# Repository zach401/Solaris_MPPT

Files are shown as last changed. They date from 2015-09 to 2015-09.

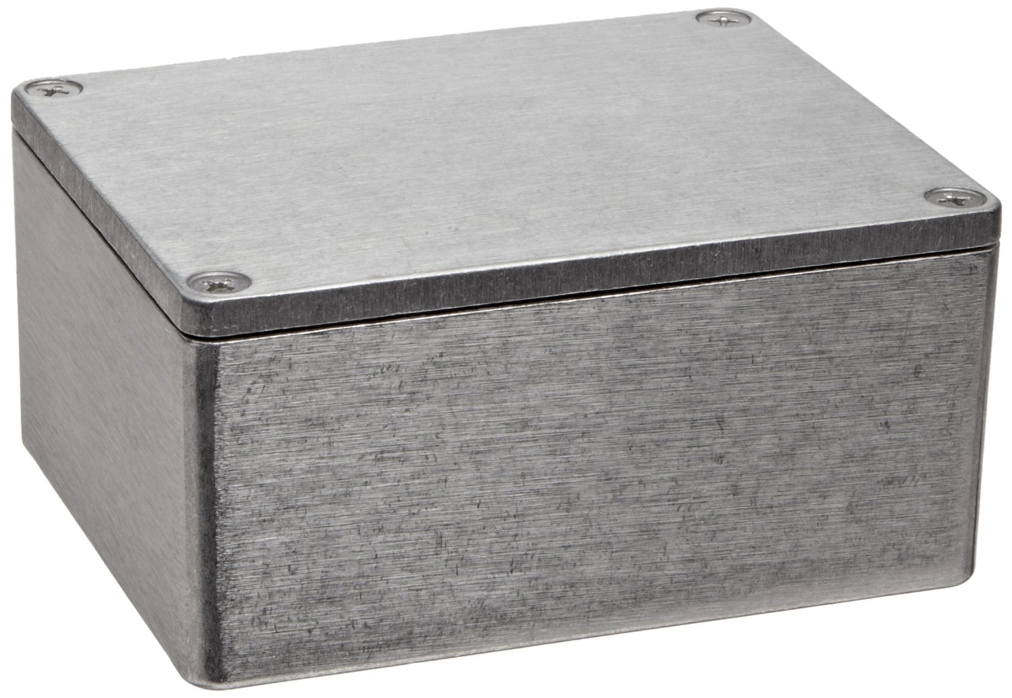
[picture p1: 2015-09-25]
Prototype Pictures, Videos/casing.jpg

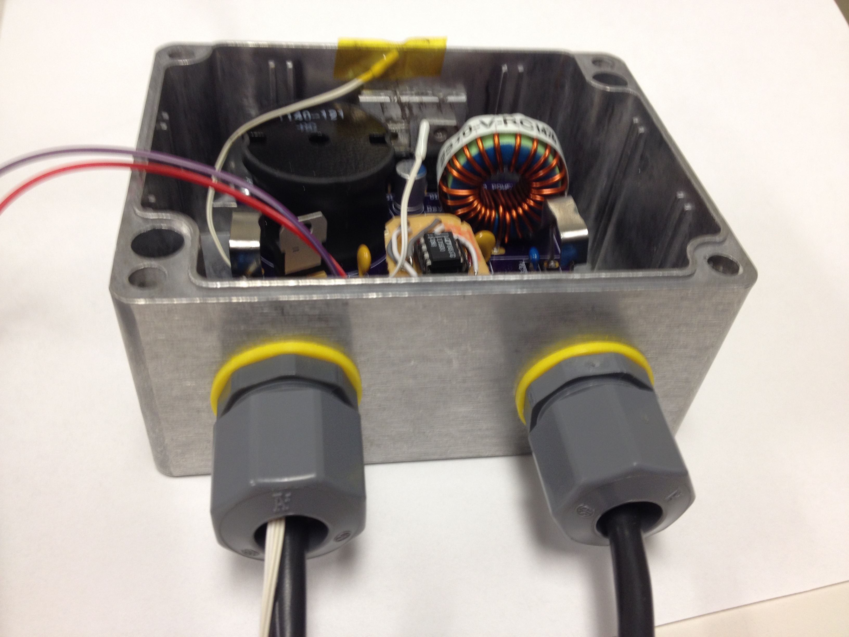
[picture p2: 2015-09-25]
Prototype Pictures, Videos/photo 4.JPG

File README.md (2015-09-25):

# Solaris_MPPT
A low-cost solar maximum power point tracker. 

#Team
Kyle Crouse | Zeke Zumbro | Austin Ricks | Zachary Lee

#Code
The microprocessor using in this project is the TI MSP430G2553 which is standing in the TI MSP430 Launchpad. C code to run the MPPT using the Perturb and Observe algorithm can be found in the Code folder. This is setup as a TI CodeComposer project.

#Electrical Hardware
Designs for the Cuk DC-DC converter, sensors, and printed circuit board for this project as well as datasheets for components can be found in the Electrical Hardware folder. 
*Note that the PCB design is rev1 which had a few mistakes including miswired pins for the OP-AMP read the Errata file for more info.

#Mechanical Hardware
Designs for a waterproof casing and heat-sink for the design can be found in the Mechanical Hardware folder.

#LTSPICE
Simulations of DC-DC converter and sensors.

#Matlab
Matlab files to calculate component values for Cuk and SEPIC DC-DC converters.

#Final Report Documents
This project was begun as a junior design project at John Brown University, as such, a detailed final report and presentation can be seen in this folder.

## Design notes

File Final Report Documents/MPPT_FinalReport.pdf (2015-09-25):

John Brown University

### Development of a Low-Cost Maximum Power Point Tracker for Low-Wattage Photovoltaic Systems

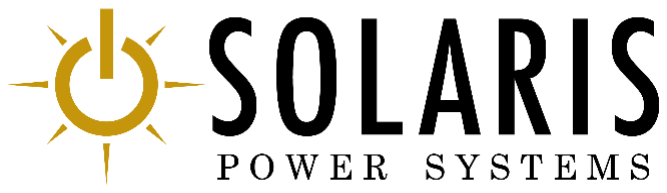
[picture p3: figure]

FINAL REPORT

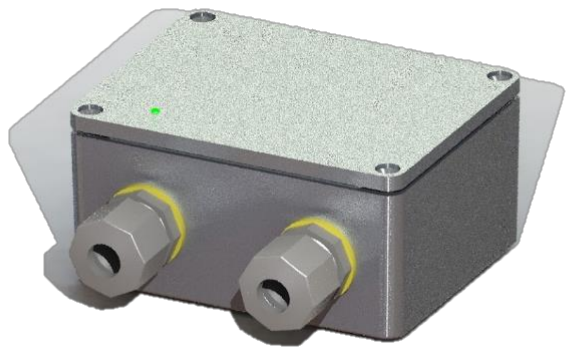
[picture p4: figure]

Kyle Crouse, Zach Lee, Austin Ricks, Zeke Zumbro Professor Kim Cornett
May 5, 2015

May 5, 2015
Final Report
ABSTRACT

The power obtained by photovoltaic panels typically is not the maximum power that could be produced by the panel. Maximum Power Point Trackers (MPPTs) have been developed in order to increase the power output of a panel by setting its operating point to the panel to the point where maximum power is extracted from the panel. The major issue with current Maximum Power Point Trackers is their high cost. The report outlines the design, assembly, and testing of a $91.32 prototype for a 65 W maximum power point tracker. Reasons for the design as well was market considerations are first discussed to justify the need for this design. Initial design parameters including technical and financial considerations are then outline for the project. The design of each subsystem, including the DC-DC converter, current and voltage sensors, algorithm, printed circuit board (PCB), and housing, are then discussed in detail. This design process includes the equations, diagrams and computer simulations used in the design process. Explanation of the construction and debugging process follows this design process. Included in this section is the creation of two small breakout boards, called stamps, which were used to correct errors in the original PCB. The report then outlines the methods used to test the MPPT, including subsystems testing and final design testing. From this testing it was determined that the circuit performed as expected when tested using a 15 W PV panel. From this testing an average power increase of 35.24%, which exceeded the design parameter of 10% power increase. Future work will include testing the design to its full rated power using a 65 W panel. However, all components are designed to exceed this power rating. Additional future work is also outlined, including increasing the efficiency of the DC-DC converter used in this design and decreasing the switching frequency used. A final production cost for 1000 units was calculated to be $40.66 which was below the desired final production cost of $75.

May 5, 2015

CONTENTS
I. Introduction | 1
II. Problem Definition | 2
A. Requirements Breakdown | 3
B. Constraints | 4
C. Testing Plan | 4
III. Technical Solution | 6
A. Brainstorming of Multiple Ideas | 6
B. Selection of Design Ideas to Pursue | 7
C. Technical Analysis & Design Details | 10
1. Electrical Details | 10
2. Mechanical Details | 21
D. Reliability & Safety (FMECA) | 25
E. Prototype Construction & Integration | 32
F. Testing & Verification | 34
IV. Schedule & Modifications | 38
V. Final Budget & Future Production Costs | 39
VI. Future Work Improvements | 42
VII. Conclusions | 43
VIII. Reflection | 43

FIGURES

Fig. 1. Cuk Converter Topology | 11
Fig. 2. LTSPICE Simulation of Ćuk Converter with Varying Duty Cycles | 12
Fig. 3. Voltage Divider with Op-Amp Buffer | 14
Fig. 4. Inverting Amplifier Configuration | 14
Fig. 5. Current Shunt Resistor Configuration | 15
Fig. 6. Ćuk Converter with Integrated Sensors | 16
Fig. 7. Linear Regulator Configuration | 17
Fig. 8. Printed Circuit Board Layout | 18
Fig. 9. Flow Chart of Perturb and Observe Algorithm [1] | 20
Fig. 10. Top View of Enclosure Box and Lid Draft and Dimensions | 21
Fig. 11. Side Views of Enclosure Box and Lid Draft and Dimensions | 22

May 5, 2015

Fig. 12. Heat Spreader, PCB Standoff Screw Draft and Dimensions | 23
Fig. 13. Cable Gland Assembly | 24
Fig. 14. Cable Gland Components Side View, w/o Plastic/Rubber Clamp Bit | 24
Fig. 15. PCB Assembly with Select Components | 24
Fig. 16. Final Product Assembly with Lid | 25
Fig. 17. Final Product Assembly without Lid | 25
Fig. 18. MPPT Test for 15 W PV Panel at Station 10 | 36
Fig. 19. MPPT Test for 15 W PV Panel at Station 9 | 36
Fig. 20. Timeline | 38

TABLES

Table I. Commercial MPPT Prices | 1
Table II. Technical Criteria | 3
Table III. Modified Technical Criteria | 3
Table IV. DC-DC Converter Decision Matrix | 7
Table V. Algorithms Decision Matrix | 8
Table VI. Current Sensor Decision Matrix | 8
Table VII. Voltage Sensor Decision Matrix | 9
Table VIII. Controller Decision Matrix | 9
Table IX. Converter Parameters | 10
Table X. Component Values | 11
Table XI. Ideal Outputs | 12
Table XII. Maximum Specifications for Components | 13
Table XIII. Selected Components | 13
Table XIV. ADC Calibration Data | 19
Table XV. FMECA Summary | 30
Table XVI. Duty Cycle Testing Results | 34
Table XVII. Efficiency Testing Data | 34
Table XVIII. Budget | 39
Table XIX. Bill of Materials | 40

May 5, 2015

I. INTRODUCTION
Photovoltaic (PV) systems are an increasingly popular source of power today, as they can be completely independent of an electrical grid, produce no emissions, and require only the sun as a fuel source. These advantages also make PV systems a viable way to alleviate energy poverty in the developing world. However, those lacking access to a reliable energy are often prohibited by the initial cost required by such PV systems. The use of a maximum power point tracker (MPPT) for PV panels can decrease this initial cost by increasing the efficiency of each panel, thus necessitating fewer panels to achieve the required power budget.
While PV systems are widely recognized as an optimal source of power in developing countries, communities in these countries are yet faced with two issues regarding the implementation of such systems: 1) the power provided by PV systems is inadequate to fulfill the total need for a community, thus necessitating kerosene or other fossil fuels as supplemental power, or 2) the community lacks the necessary funds to make the initial investment for a PV system. A PV system typically consists of one or more PV panels connected to a battery. By introducing an MPPT into a PV system, the efficiency of each panel is optimized, increasing the power output relative to PV systems without maximum power point tracking. To a community presently possessing a PV system, adding an MPPT drastically increases the power produced by the system for the community, reducing the community’s need for fossil fuels as supplemental power. To a community considering the purchase of PV panels, the addition of an MPPT reduces the initial investment required, as fewer panels are necessary to achieve the desired power budget.
This project fits within the Environmental Technology market segment. The target market for this project is home and business owners in the developed and developing world who utilize low-wattage PV systems to provide electricity and reduce their environmental impact. This project is primarily focused on consumers in the developing world who cannot afford MPPTs on the market today. Table I shows the current costs of MPPTs on the market today.

Table I. Commercial MPPT Prices

Name

Max Power
Intake (W)

Price ($)

BZ Products MPPT250 | 300 | 111
Blue Sky 2512i | 300 | 213
Morningstar SunSaver 15 Amp MPPT Solar Charge Controller | 180 | 250
Rogue MPT-3048 | 360 | 350
Morningstar TriStar 30 Amp MPPT Solar Charge Controller | 360 | 355

May 5, 2015

From Table I it can be seen that most MPPTs on the market today cost over $100, which is out of the price range of many in the developing world. A high priced MPPT makes the purchase of an additional panel more cost effective than adding an MPPT. This project seeks to develop a more affordable MPPT to meet this market need. This device will be important for this market as it decreases the cost per watt of PV systems by increasing the power output of a PV system at a lower cost than adding the equivalent capacity by adding additional PV panels. This device will thus help to provide access to affordable electricity in developing regions. The project will also have a broader market toward any PV user desiring to maximize the efficiency of his or her PV system at the lowest cost.
This report details the design, construction, and testing process of a low-cost MPPT appropriate for small PV systems in developing countries. The resulting MPPT is designed to receive as input a PV panel or array with a maximum capacity of 100 W. The MPPT which has been designed is extremely simple and does not include any additional features which would increase cost and add additional points of failure. The design is water resistant and robust against physical damage.
As a result of this project a working MPPT has been developed which has demonstrated the ability to increase the power to a resistive load by an average of 35.24%.The MPPT has been tested extensively with a 15 W PV panel and has been tested on a 65 W panel. Each subsystem of the MPPT has been thoroughly tested, including the DC-DC converter, current and voltage sensors, and housing. Although the initial design parameters were changed after consulting with Dr. Song, all of these new parameters were met with the exception of the efficiency standard for the DC-DC converter. It was found that the DC-DC converter for this design was 75% efficient which exceeded the initial requirements. A detailed user’s manual as well as packaging have also been created for this project.

II. PROBLEM DEFINITION
MPPTs increase the power output of PV panels, however due to the high costs of many on the market they are not economically viable for small solar arrays; this creates a need for a lower cost option. The proposed project would decrease the cost of the MPPT to $75 by utilizing a low-cost microprocessor, low-cost sensing technologies, and by custom designing components as necessary. The MPPT will be designed with widely available, modular components, to allow for ease of maintenance and repair. Additionally, the MPPT will be designed to have a plug-and-play interface, so as to simplify installation and setup. As PV systems are necessarily outdoors, the MPPT will be housed in such a way as to withstand adverse weather conditions, such as rain and extreme temperatures.

May 5, 2015

A. Requirements Breakdown
The initial technical performance criteria for this project can be seen in Table II.

Table II. Technical Criteria
| Min | Max
Vin | 5 V | 38 V
Vout* | 11.8 V 14.4 V
∆Vout | - | 2.5%
P | - | 300 W
∆P | +10% | -
Efficiency | 90% | -
Self-Consumption - | 50 mW
Length | - | 8"
Width | - | 6"
Height | - | 4"

After consulting with our mentor Dr. Ted Song, and doing preliminary research, these criteria were adjusted to more realistic levels for a one-semester undergraduate project. In addition, the load for the project was changed from a battery load to a resistive load. These new criteria can be seen in Table III.

Table III. Modified Technical Criteria
| Min | Max
Vin | 5 V | 40 V
Vout* | 0 V | 25 V
∆Vout | - | N/A
P | - | 100 W
∆P | +10% -
Efficiency | 70% | -
Self-Consumption - | 100 mW
Length | - | 8"
Width | - | 6"
Height | - | 4"

The criteria of Vin was determined based on the minimum and maximum voltage outputs for PV panels in the 100 W range. The criteria for Vout was determined based on realistic values for voltage across the output resistor when tracking the maximum power point. This is the type of battery system expected to be used by the target market, as it is an affordable energy

May 5, 2015

storage technology. The output voltage ripple was determined not be important for this design as the output voltage would fluctuate as the MPPT operated regardless of the output capacitor. However, for calculations to determine the output capacitor an allowable voltage ripple of 2.5% was used. The minimum ∆P criteria of +10% means that the MPPT should increase the power output of the panel by at least 10%. The purpose of the MPPT is to increase the power output of the PV panel, thus this minimum is an important criteria for determining the success of the design. The criteria for minimum efficiency of the DC-DC converter within the MPPT has been set to be 70%. The goal of a MPPT is the increase of efficiency of the PV system, thus inefficiencies within the DC-DC converter must be minimized. However, extremely efficient DC-DC converters are difficult to design and outside the scope of this one-semester project, so an allowable efficiency of 70% is realistic. The criteria for self-consumption, or the power taken to run the MPPT, will be less than 100 mW. This too is important because power used to run the controller and other components contributes to inefficiency of the MPPT, and thus should be minimized. Finally, the mechanical size constraint of 8” x 6” x 4” for the device was determined to reduce the footprint of the device where it is installed and to ensure that the device can be easily transported.
B. Constraints
1) Production cost must not exceed $75. As previously stated, a key goal for this project is to design an MPPT that is substantially lower in cost than comparable MPPTs on the market today, making this a primary constraint on the design.
2) Prototype cost must not exceed $150. Since electrical components and printed circuit board fabrication reduce significantly at production quantities, it is expected that the prototype will cost more than a production model of this MPPT. A $150 budget has been determined for this prototype based on the money provided by John Brown University as seed funding for this project.
3) Prototype must be weather resistant. PV panels are necessarily outdoors, thus making it highly likely that the MPPT will be outdoors as well. Without weather resistance, the MPPT will quickly break down and fail to function. The MPPT may be mounted inside of buildings to which power is supplied, but this is not guaranteed. In circumstances when this is not available, the product will be designed to be weather resistant.
4) Design must prevent electric shock to users. Users should not be shocked when installing the device, nor should technicians be shocked when servicing the device.
5) Prototype must be completed by May 5.
C. Testing Plan
In order to determine if the prototype conformed to the design requirements, tests were designed to analyze each subsystem as well as the system as a whole. Testing of the DC-DC

May 5, 2015

converter subsystem was done first in order to determine proper functionality and an acceptable efficiency. The operation of the DC-DC converter was tested by attaching the input side of the converter to a DC voltage source. An MSP430 was then will be used to provide pulse width modulation (PWM) waveform to the DC-DC converter. The output of the DC-DC converter was then measured across a load resistor using the Digital Multimeter (DMM). Success of the DC-DC converter was determined based on whether or not the output voltage was able to be controlled by the PWM signal provided by the AWG. The efficiency of the DC-DC converter was also tested by measuring the input voltage and current to the DC-DC converter using the DMM to find the input power. This was compared to the output power calculated using the load resistance and output voltage measured using the DMM. The circuit was determined to be successful if the efficiency was greater than 70%.
The controller subsystem was also tested. The first elements of the controller subsystem to be tested was the voltage and current sensors. Each sensor was evaluated by providing to it a known voltage or current using a DC voltage source and resistors. The output of the sensor was then compared to the reading from a DMM to determine if the output voltage of the sensor was linearly related to the input. The output of each sensor was then read using the MSP430 ADC. Linear regression was then used to relate the ADC values to the actual voltage and current values read by the DMMs.
The mechanical case subsystem was also tested. The case subsystem was primarily tested for weatherproofing. To do this the case was sealed and water will then be poured over the case in a way which simulated heavy rainfall. The case was then opened and examined to determine if water was able to penetrate the case. The casing was considered successful if no evidence of leakage is found after testing for 1 hour.
Finally the integrated system was tested. Temperature testing was conducted using the PCB circuit inside of the sealed housing. Two thermocouples were used to read temperature levels as the circuit was given power. Maximum temperatures of the individual circuit components were found from the data sheets. This indicated a maximum circuit temperature of 185℉. Testing results that produce an equilibrium temperature less than the 185℉ maximum will be successful.
The effectiveness of the MPPT will be evaluated by determining the increase in power provided to the load when using the MPPT versus when a resistor is directly connected to the panel. The panels connected to MPPT and resistor will then be swapped so each is connected to each panel. The results of these tests will be compared to eliminate variations from different PV panels. The MPPT was considered successful if the average output power was at least 20% higher than the average output power of the PV panel connected directly to the load.

May 5, 2015

III. TECHNICAL SOLUTION
A. Brainstorming of Multiple Ideas
The basic design of a MPPT has been well established, so there was no need to brainstorm alternatives to this design. However the subsystems of the design had many alternatives. There are six major subsystems for which brainstorming alternatives was necessary. The first of these was the DC-DC converter. Five alternatives for the DC-DC converter were determined based on the converters which were covering in EE3503 Power Electronics. These converters were Buck, Boost, Buck-Boost, Ćuk, and SEPIC. The next major subsystem was the algorithm. Based on previous research three alternatives were established. These were Perturb and Observe, Incremental Conductance, and Fractional Open Circuit Voltage. The next subsystem to be considered were sensors. For current sensors three options were considered; a shunt resistor, a Hall Effect current sensor, and a fiber optic current sensor. For voltage only two alternatives were available. These were using the microcontroller's ADC with a resistive divider, and using a voltage measurement integrated circuit. For the controller subsystem four alternatives were developed; an MSP430, a digital signal processor, an FPGA, and an Arduino.
The final subsystem for which alternatives were brainstormed was the housing. Ideas for housing material included printed ABS, purchased injection molding plastic enclosures, purchased extruded aluminum enclosures with outward facing fins, aluminum sheet metal, and purchased ammunition boxes. At the start, plastic was the favored material because it would be easier to work, would not heat up enough to burn the user, and would meet water-resistance and debris resistant requirements. However, aluminum was chosen because it is not difficult to machine, requires a significant amount of heat to burn the user that the circuit is not expected to produce, can be made to fit all durability requirements, and is able to conduct heat better than typical ABS plastic can. As for cable input and output into the housing, not a lot of valid ideas were thought of that would provide strain relief and weather resistance. The way coax cables are used was looked at as a reference but turned down for lack of application to the product concept. The next idea was to use cable glands, which use a double threaded shell of PVC and a nut that compresses a plastic and rubber bit onto the cable. For heat dissipation, the ideas looked at were vents in the bottom of the housing, a small fan to circulate interior air, and circuit components sinking heat directly into the enclosure wall. For mounting, the ideas were surface mounting, pole mounting, and solar array frame mounting. Finally, the alternatives to have a lid or not to have a lid were determined, including what type of lid attachment should be used. Attachment ideas included clamping using jar hooking clamps on all side or with a hinge on one side, a draw latch with hinge, or screws between the lid and box. Each subsystem was then analyzed to determine what criteria should be used to select each component. The components were then run through a decision matrix in order to determine which alternative would be used.

May 5, 2015

B. Selection of Design Ideas to Pursue
The decision matrix in Table IV outlines the selection of a DC-DC converter topology. Four criteria were developed to evaluate the five alternatives. These criteria were cost, simplicity, inversion, and flexibility. The cost criteria involves the costs of components needed for the DC-DC converter design as well as the size of the PCB required, as this will increase the total cost. A higher score in this category signifies a lower cost. The simplicity criteria involves how difficult the design will be as well as difficulty in controlling the converter. Simplicity scores are higher for designs which do not require driver ICs for high-side switching, as well as for designs with fewer components. The inversion criteria grants higher points to converters which do not invert the output. Finally, the flexibility criteria grants higher scores to converters which are able to handle inputs which are both higher and lower than the output and lower scores to converters which can only increase or only decrease voltages. The points in the total column are highest for the best design, which in this case is the SEPIC and Ćuk converters. Since cost was a prime factor, the Ćuk Converter was finally chosen for this design.

Table IV. DC-DC Converter Decision Matrix

DC-DC Converters Cost Simplicity Inversion Flexibility Total
Buck | 7 | 5 | 10 | 5 | 20
Boost | 9 | 9 | 10 | 3 | 22
Buck-Boost | 7 | 5 | 7 | 10 | 22
Cuk | 5 | 7 | 7 | 10 | 24
SEPIC | 3 | 6 | 10 | 10 | 24

The decision matrix in Table V outlines the selection of a MPPT algorithm for the design. Six criteria were developed to evaluate the three alternatives. These criteria were simplicity, required sensors, computational resources, effectiveness, speed, and flexibility. The simplicity criteria measures the ease with which the algorithm can be implemented in code. The simplicity score is highest for algorithms which are easily implemented and lowest for algorithms which are more difficult to implement. The required sensors criteria involves the number and types of sensors required for the algorithm. Perturb and Observe and Incremental Conductance both score poorly in this area because they require a current sensor and voltage sensor, while Fractional Open Circuit Voltage only requires a voltage sensor. The computational resources criteria measures how much processing power is needed to implement the algorithm. This is measured by the number of operations which are necessary in each loop. A higher score in this category represents fewer operations needed. The effectiveness criteria represents how accurately the algorithm find the correct maximum power point (MPP). This score is highest for the Incremental Conductance method which finds and latches on to the MPP. The Perturb and Observe algorithm is next highest since it

May 5, 2015

find the MPP but oscillates around it. Finally, the Fractional Open Circuit Voltage method is least effective as it only approximates the MPP. The speed criteria represents how quickly the algorithm is able to find the MPP. A higher score in speed means that the algorithm find the MPP faster. The flexibility criteria is rates the algorithms on their ability to work with different PV panels without calibration. Since the Fractional Open Circuit Voltage method relies on specifics about the panel, it scores poorly in this category, while the other two algorithms score well. From the total column in Table V it can be seen that the Perturb and Observe method is preferable, and thus this algorithm was chosen for this design.

Table V. Algorithms Decision Matrix

Algorithms | Simplicity

Required
Sensors

Computational
Resources
Effectiveness | Speed | Flexibility Total
Perturb | and
Observe
8 | 6 | 9 | 9 | 8 | 10 | 50

Incremental
Conductance
7 | 6 | 7 | 10 | 9 | 10 | 49

Fractional Open
Circuit Voltage
10 | 10 | 10 | 6 | 10 | 2 | 48

The decision matrices in Table VI and Table VII outline the selection of current and voltage sensors for the design. The criteria for both matrices are the same: cost, simplicity, reliability, and efficiency. The cost criteria relates to the cost of the sensor or components to build the sensor. A higher score represents a lower cost. The simplicity criteria involves how difficult the sensor will be to design and implement, as well as the ease with which the sensor can be read by the controller. A higher simplicity score represents a simpler design. The accuracy criteria represents how accurate the sensor is relative to the actual value, with a higher accuracy score meaning that the sensor is more accurate. The efficiency criteria measures how much power is consumed by the sensor. A higher score in efficiency represents a lower power consumption for the sensor. From Table VI it can be seen the both the Shunt Resistor and Hall Effect sensor have the same total score. The Shunt Resistor and Amplifier has been selected however, due to greater simplicity. From Table VII it can be seen that the Microcontroller ADC with Voltage Divider method received the highest score and will be used for this project.

Table VI. Current Sensor Decision Matrix

Current Sensors | Cost Simplicity Accuracy Efficiency Total
Shunt Resistor and Amplifier 8 | 7 | 7 | 6 | 27
Hall Effect Current Sensor | 7 | 4 | 8 | 8 | 27
Fiber Optic Current Sensor | 1 | 1 | 10 | 8 | 20

May 5, 2015

Table VII. Voltage Sensor Decision Matrix

Voltage Sensor | Cost Simplicity Accuracy Efficiency Total
Microcontroller ADC and Voltage Divider 9 | 10 | 8 | 6 | 34
Voltage Measurement IC | 7 | 7 | 9 | 9 | 32

The decision matrix in Table VIII outlines the selection of a controller. The criteria for controller selection are cost, processing power, ease of programming, power consumption, and peripherals. For the cost criteria, a higher score in the represents a lower cost. The processing power criteria represents the amount of processing power the controller has, such as its clock speed and the ability to perform tasks in parallel. High scores in this category represent high processing power. The ease of programing criteria takes into account the ease with which the algorithm can be implemented on the controller. This includes the language which is used to program the controller, development environments available to be used when programming the controller, and availability of sample code. High scores in ease of programming correspond to simpler implementation, a strong development environment, and access to sample code. The power consumption criteria takes into account how much power each controller would require. Since self-consumption of the MPPT has been limited to below 100 mW, it is important that power consumption of the controller be kept low. A high score in power consumption relates to a low power consumption. Finally, the peripherals criteria takes into account the presence of peripherals available on the controller, including ADCs, PWM generators, etc. High scores in this category were given to controllers with these peripherals. From the total column of Table VIII it can be seen that the MSP430 microcontroller received the highest score, and will be used as the controller for this project. This also aligns with the SURF grant which is providing additional funds for this project, as the grant specifies that an MSP430 be used.

Table VIII. Controller Decision Matrix

Controllers | Cost Processing Power Ease of Programming Power Consumption Peripherals Total
MSP430 | 10 | 6 | 9 | 9 | 9 | 43
Digital Signal Processor 8 | 8 | 7 | 7 | 10 | 40
FPGA | 4 | 9 | 7 | 5 | 8 | 33
Arduino | 6 | 6 | 10 | 7 | 9 | 38

May 5, 2015

The criteria for housing of the printed circuit board include weather resistance, durability, and prevention of electrical shock to the user. Additional desired characteristics of the housing design include affordability, ease of manufacture, use of common materials to provide for simple and quick maintenance, reversible component attachments, adequate heat dissipation for the PCB, and durable mounting into the PV array circuit. Since the project is still in the design phase, alternatives that match these constraints and goals are not available and additional research will be made that will affect design choices in the future. Housing design manufacture is scheduled for 20 March 2015. Testing is scheduled for 12 April 2015, and the results will affect the final prototype design for final presentation on 5 May 2015. At the time of proposal submission, plastic is the favored material for circuit housing to minimize cost and weight. Metal housing would heat up in the summer, hindering heat dissipation from the circuit, and would need to be properly sealed to prevent rust. A hinged lid with O-ring sealing is an alternative that would allow for ease of access to the circuit while keeping the circuit weather resistant. Additional research and future design alternatives will be included in the online project notebooks.
The criteria for housing of the printed circuit board include weather resistance, durability, and prevention of electrical shock to the user. Additional desired characteristics of the housing design include affordability, ease of manufacture, use of common materials to provide for simple and quick maintenance, reversible component attachments, adequate heat dissipation for the PCB, and durable mounting into the PV array circuit.
C. Technical Analysis & Design Details
1. Electrical Details
Technical analysis of the chosen design began by determining the DC-DC converter parameters needed in the design. These parameters can be seen in Table IX. The values in Table IX were selected based on PV panel characteristics as well as research into parameters of other comparable MPPTs.

Table IX. Converter Parameters
Parameter Minimum | Maximum
Vs (V) | 5 | 38
R (Ω) | 1.44 | 7.5
D | 0.24 | 0.75
f (kHz) | 100 | 200
ΔVC1 (V) | - | 0.1
ΔVC2 (V) | | 0.25

May 5, 2015

A Ćuk Converter topology was selected for the DC-DC converter. A diagram of the Ćuk topology can be seen in Fig. 1.

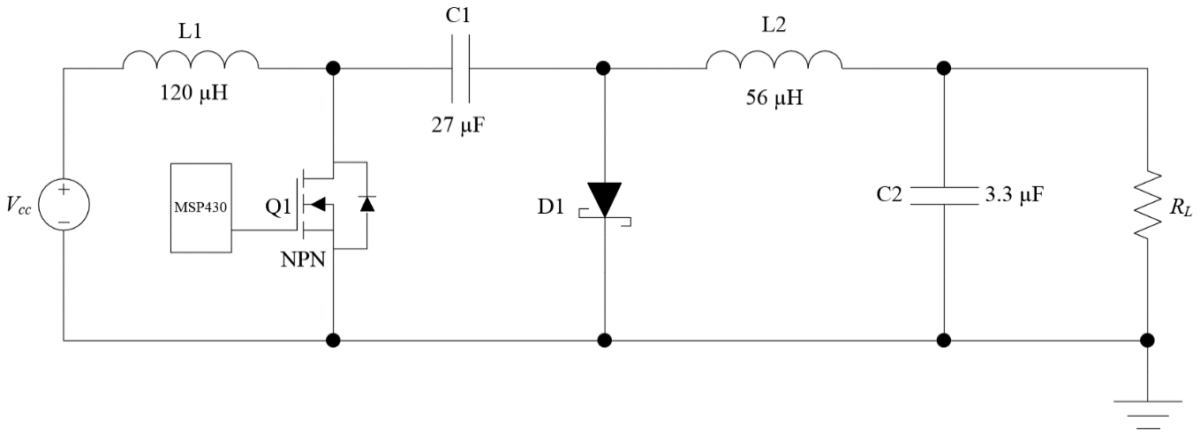
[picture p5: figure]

Fig. 1. Cuk Converter Topology

The values of L1, L2, C1, C2 were found using equations (1) through (4).

L1 ≥

Rmin(1 − Dmin)²

2Dmin ∗ fmin

(1)

L2 ≥

Rmax(1 − Dmin)
2fmin

(2)

C1 ≥

Dmax
Rmin ∗ fmin ∗ ∆VC1

(3)

C2 ≥

1 − Dmin
8 ∗ ∆VC2 ∗ L2 ∗ fmin
2 | (4)

The results of these equations can be seen in Table X. Note that the values in the table are minimum values.

Table X. Component Values
Parameter | Value
L1 | 120 μH
L2 | 38 μH
C1 | 26 μF
C2 | 2.5 μF

May 5, 2015

LTSPICE simulations were then used to determine if the calculated values gave the desired function of the circuit. This was done by modeling the circuit in LTSPICE then using the STEP command to vary the duty cycle of the MOSFET from 20% (teal) to 70% (grey). The plots of the DC-DC convert output for the varying duty cycles can be seen in Fig. 2. A table of the ideal output for each duty cycle can be seen in Table XI. These values were calculated using equation (5) which is the ideal relationship between input and output for a Ćuk converter. By comparing the values from Fig. 2 and Table XI, it can be seen that the circuit functions as expected. The small discrepancies between the ideal output and the simulated output are due to non-ideal switches, including the voltage drop across the diode.

Vo = Vs ( D
1−D) | (5)

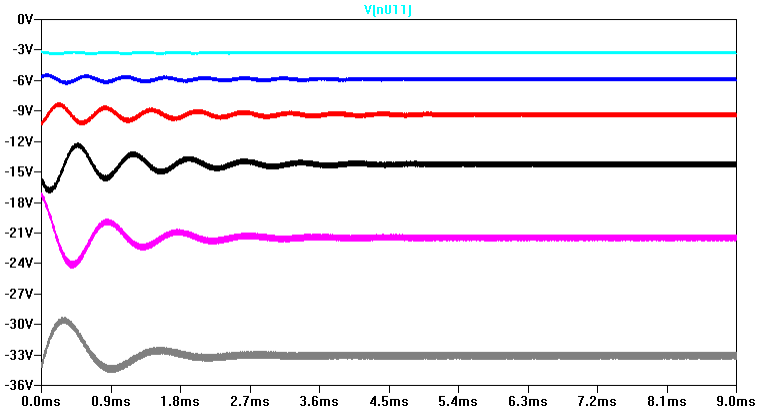
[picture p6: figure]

Fig. 2. LTSPICE Simulation of Ćuk Converter with Varying Duty Cycles

Table XI. Ideal Outputs
Duty Cycle | Ideal Output | Color
20% | -3.75 | Teal
30% | -6.42857143 | Blue
40% | -10 | Red
50% | -15 | Black
60% | -22.5 | Pink
70% | -35 | Grey

May 5, 2015

After it was determined that the circuit functioned as designed, maximum current and voltage rating for each component were determined from the LTSPICE model. These max specifications can be seen in Table XII.

Table XII. Maximum Specifications for Components
Component | Max Voltage (V) | Max Current (A)
L1 | 16 | 8
L2 | 21 | 3
D | 20 | 10
C1 | 20 | 9
C2 | 20 | ~0.5
M1 | 27 | 10

Using the minimum values from Table X and the specifications from Table XII components were selected from www.digikey.com. Values and specifications of the selected components can be seen in Table XIII.

Table XIII. Selected Components
Component | Value | Max Voltage (V) | Max Current (A)
L1 | 120 uH | - | 9.9
L2 | 56 uH | - | 10.2
D | - | 60 | 10
C1 | 27 uF | 63 | -
C2 | 3.3 uF | 25 | -
M1 | | 75 | 100

In addition to the DC-DC converter. Voltage and current sensor were also needed for this design. It was determined that using the ADC built in to the MSP430 offered the easiest and lowest cost solution for voltage and current sensing. A reference voltage of 1.5 V was selected for the ADC. In order the scale the input voltage from a range of 0 to 38 V to a range of 0 to 1.5 V, a voltage divider was used. A diagram of this resistive divider topology can be seen in Fig. 3.

May 5, 2015

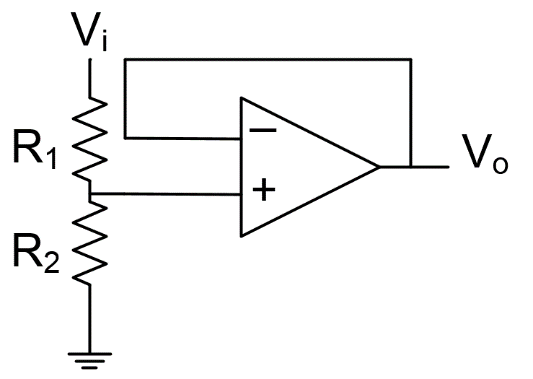
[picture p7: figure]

Fig. 3. Voltage Divider with Op-Amp Buffer

It was determined that a voltage of 64 V should correspond to 1.5 V on the voltage divider. An input/output ratio of 0.0234 was thus determined for the voltage divider. Using equation (6), values of R1 = 470 kΩ and R2 = 11 kΩ were selected from available resistors. This corresponded to an input/output ratio of 0.029. Large resistors were selected for this application in order to limit current through the voltage divider. An OP-AMP was used to buffer the output of the voltage divider before passing the signal to the ADC for reading.

Vo
Vi

= R2
R1+R2

(6)
For the output voltage sensor the voltage needed to be inverted as well as scaled since the output of a Ćuk converter is negative. This was accomplished using an OP-AMP inverting amplifier configuration. This configuration can be seen in Fig. 4. Equation (7) can be used to find the input/output relationship for the inverting amplifier. For ease of programming, it was determined that it was best to keep the same ratio for both input and output voltage sensors. Thus using (7) the values of R1 and R2 were determined to be R1 = 47 kΩ and R2 = 1.1 kΩ. Lower values were selected for R3 and R4 versus R1 and R2 since these resistors did not provide a path to ground, and thus excess current traveling through them was not a concern.

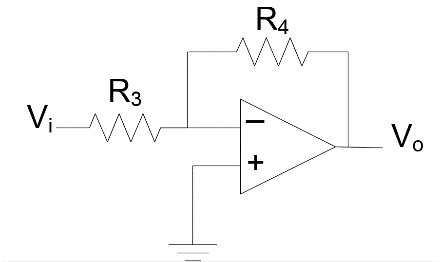
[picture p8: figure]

Fig. 4. Inverting Amplifier Configuration

Vo
Vi

= − R4
R3

(7)

A shunt resistor was determined to be the easiest way to measure current in the design. A shunt resistor is a small resistor which is placed in series with the load. The current traveling through the load is proportional to the current flowing through the load. A 5 mΩ shunt

May 5, 2015

resistor was chosen. However, even at max rated current of 10 A, the voltage across this 5 mΩ resistor would be only 50 mV. In order to amplify this signal a current shunt monitor was used. This current shunt monitor amplified the voltage across the resistor with a gain of 20, thus putting the signal within a range which could be read by the ADC. A diagram of this current sensing topology can be seen in Fig. 5.

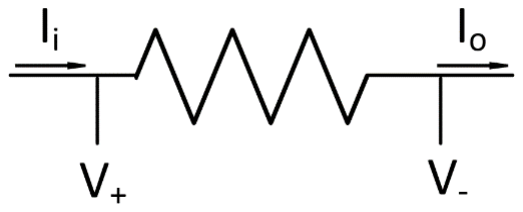
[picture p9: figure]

Fig. 5. Current Shunt Resistor Configuration

The Ćuk Converter and sensor circuits were then integrated into a final circuit. A diagram of this circuit can be seen in Fig. 6.

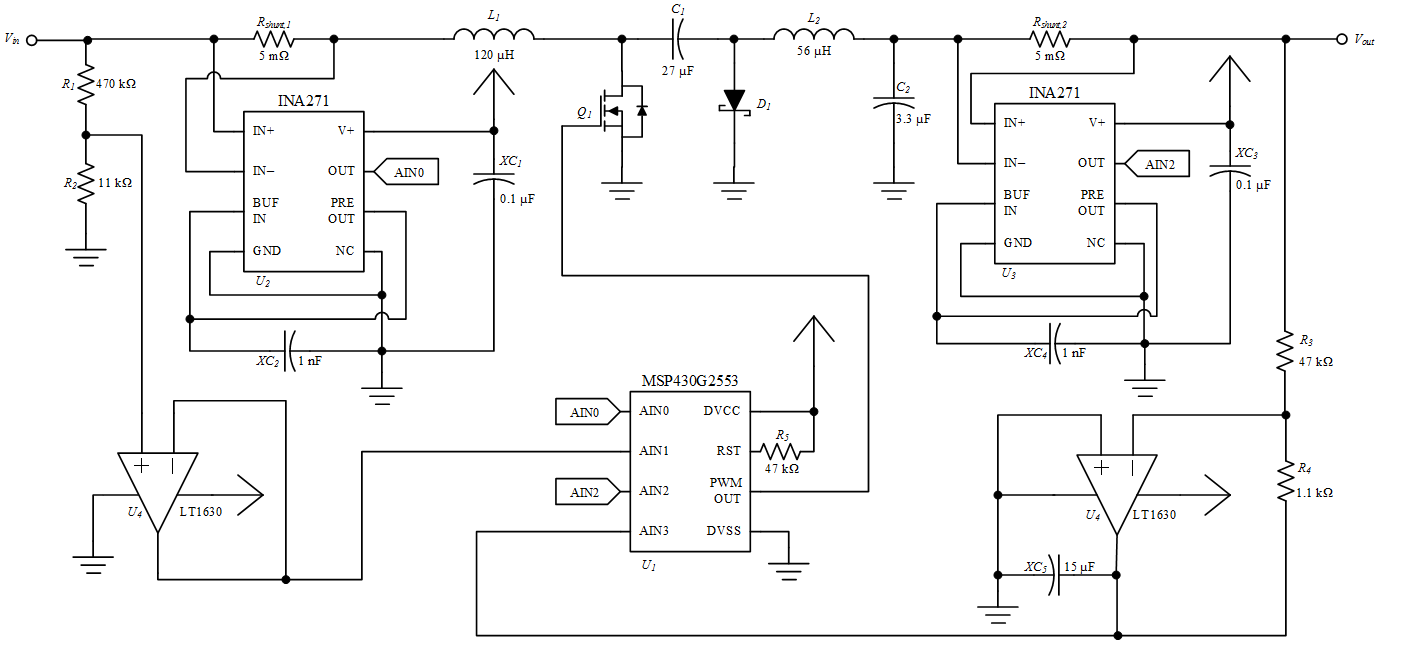
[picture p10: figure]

Fig. 6. Ćuk Converter with Integrated Sensors

In order to power the MSP430 as well as the op-amps and current shunt monitors a linear regulator was chosen. This linear regulator lowers the input voltage to a constant 3.6 V. This voltage was chosen as it is high enough to fully saturate the logic level MOSFET used in this design, which is important for using the MOSFET as a switch. Because a 3.6V regulator was not available, a variable output regulator was purchased. The voltage output of this regulator was determined based on two external resistors using the configuration in Fig. 7 and equation (8). By setting Vout equal to 3.6 and solving for R2/R1 it was found that that ratio of R2 to R1 should be approximately 1.88. Using resistor values which were then chosen from available resistors. R1 was selected to be 2 kΩ and R2 was selected to be 3.8 kΩ.

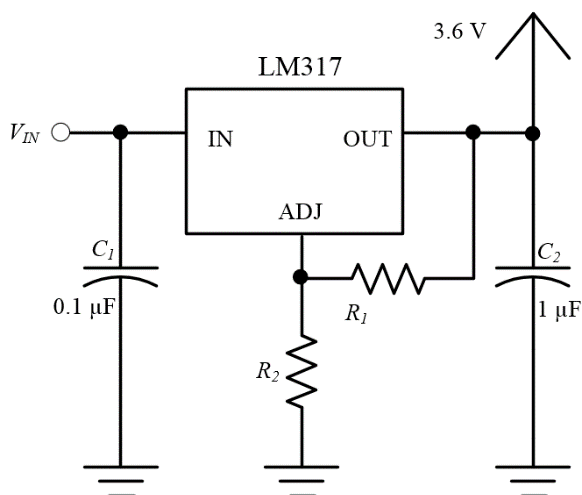
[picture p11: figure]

Fig. 7. Linear Regulator Configuration

Vout = 1.25(1 + R2
R1
) | (8)

A printed circuit board was then designed for the circuit. The required trace widths were first calculated using an online tool [2]. Two net classes were defined. The first was a power class which could handle up to 10 A of current. It was determined that having these power traces on both the top and bottom of the board would best allow for this large amount of current which minimizing the needed trace width. The second net class was a data class which did not need to handle high currents, but instead moved signals across the board. Each of the components selected from Digi-key were modeled in Eagle then used to create a schematic and then board layout. For the board layout the autorouter function was first used to begin routing traces. Traces which could not be completed by the autorouter were then completed by hand. The final PCB layout can be seen in Fig. 8.

March 12, 2015

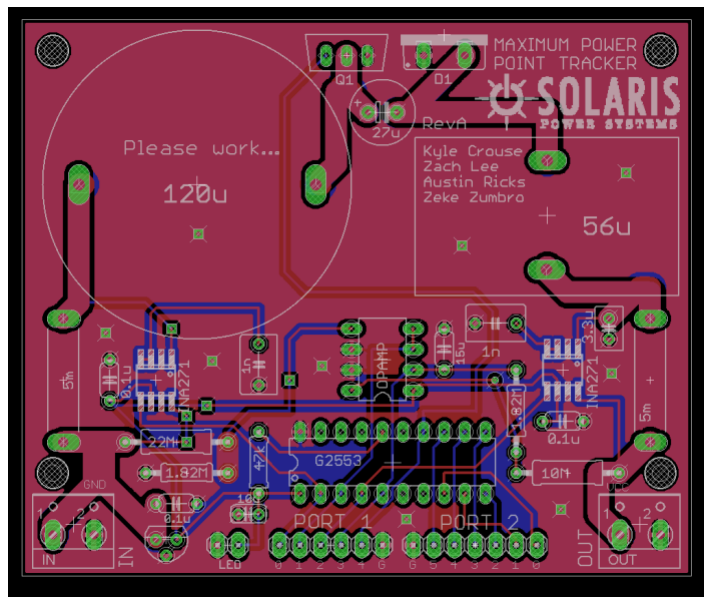
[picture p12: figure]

Fig. 8. Printed Circuit Board Layout
In addition to the electrical hardware components of this design, the software which runs on the MSP430G253 is extremely important. It is this software to enables the design to track the maximum power point, and provides the DC-DC converter with the switching signal that it needs to function. The code for this design can be seen in Appendix A. The code can be roughly divided into three sections; initialization, sensor reading, and maximum power point tracking.
The first of these divisions, initialization, contains the code which sets up the microcontroller and required peripherals. This initialization includes the functions Setup_MSP, Setup_ADC, Setup_PWM, and Setup_Timer. The initialization of each peripheral was divided into separate functions to that it was clear where the settings for each was located. This allows for greater readability of code and will make maintaining this code easier in the future. The clock speed of the MSP430 was set to 16 MHz in order to allow for the maximum number of duty cycle steps when running pulse width modulation (PWM) at 100 kHz. The ADC was configured to read 4 channels 32 times consecutively. This allowed for sampling each of the 4 sensors as well as averaging over 32 samples in order to take more accurate readings. The number of samples was chosen to be 32 since 32 is a power of 2 and thus division by 32 can be accomplished using a bit-shift which is more efficient than a normal integer division. TimerA0 was configured for PWM, and set to a frequency of 100 kHz by setting TACCR0 to
160. This value was determined by dividing the clock frequency, 16 MHz, by the desired frequency 100 kHz. PWM was set up to output on P1.6.
The next division of code was reading from the sensors. This section consists the function Read_ADC and the interrupt service routine (ISR) for the ADC. When Read_ADC is called, the ADC enable conversion flag is first cleared. The function then waits if the ADC is currently busy. The data from the ADC is then directed into an array of unsigned integers, and sampling and conversion is started. The processor is then placed into low power mode 3. When the ADC has finished sampling, the ADC ISR is called and the processor exits low power mode. After ADC measurements have been taken, the 32 samples from each sensor are first added together, then this value is divided by 32 to find the average. This average is then put through a linear equation to relate the ADC value for each sensor to its actual measurement (volts or amps). This equations were determined using linear regression from data taken during testing. In order to get this data, known voltages were fed into the input of the circuit. The current in, as well as the voltage and current out were then measured using digital millimeters. At the same time the ADC measurements taken from the sensors on the board were also read. The data from this experiment can be seen in Table XIV. The linear regression tools from Microsoft Excel were then used to find equations relating voltage or current to the corresponding ADC value. The equations relating ADC reading and actual measurements can be seen in equations (9) through (12).

Table XIV. ADC Calibration Data
Input | Output

Current (A)

Current
ADC
| | Voltage (V) | Voltage ADC | Current (A) | Current ADC | Voltage (V) | Voltage ADC
0 | 3 | 0 | 11 | 0 | 12 | 0 | 8
0.043 | 7 | 0.5 | 11 | 0.046 | 12 | 0.101 | 6
0.157 | 12 | 1 | 18 | 0.17 | 10 | 0.37 | 7
0.296 | 23 | 1.5 | 25 | 0.307 | 15 | 0.667 | 8
0.46 | 32 | 2 | 32 | 0.457 | 29 | 0.994 | 14
0.646 | 42 | 2.5 | 41 | 0.628 | 41 | 1.36 | 20
0.84 | 55 | 3 | 48 | 0.8 | 55 | 1.74 | 28
1.06 | 75 | 3.5 | 57 | 0.999 | 72 | 2.16 | 35
1.28 | 91 | 4 | 66 | 1.18 | 88 | 2.57 | 42
1.53 | 111 | 4.5 | 71 | 1.39 | 104 | 3 | 49
1.84 | 136 | 5 | 78 | 1.62 | 124 | 3.5 | 58
2.18 | 163 | 5.5 | 91 | 1.88 | 145 | 4.05 | 68
2.54 | 191 | 6 | 95 | 2.12 | 165 | 4.6 | 77
Iin = 0.013459IinADC + 0.01594 | (9)
Vin = 0.066097VinADC − 0.27437 | (10)
Iout = 0.013002IoutADC + 0.019945 | (11)
Vout = 0.061412VoutADC − 0.05239 | (12)
The final division of the program for this design was the actual maximum power point tracking function. Many MPPT functions were developed, however the one chosen for this design utilized the simplest MPPT algorithm, Perturb and Observe. A flow chart of the Perturb and Observe algorithm which was provided by Microchip can be seen in Fig. 9 [1]. In the Perturb and Observe algorithm the MPPT can be in one of two states, incrementing or decrementing. If the MPPT is in the incrementing state, then the duty cycle was last increase, if it is in the decrementing state, then the duty cycle was last decreased. In order to determine if the duty cycle would be incremented or decremented, the current instantaneous power was compared to the previous instantaneous power, if the power increased, then the state would remain the same and the duty cycle would be incremented or decremented based on its state. If the power instead decreased then the state was toggled, and the duty cycle would be incremented or decremented accordingly.
In order to make sure that the duty cycle never left its allowable range, if statements were used to make sure that the duty cycle was never incremented beyond its max duty cycle or decremented beyond it minimum duty cycle. These maximum and minimum duty cycles were set at 80% and 20% respectively. If the duty cycle was supposed to be incremented, but was already at its maximum value the duty cycle was instead decremented and the state was changed to decrement. The opposite was done if the duty cycle was supposed to be decremented but was already at its minimum value. This ensured that the MPPT would never get stuck at its maximum or minimum duty cycle.

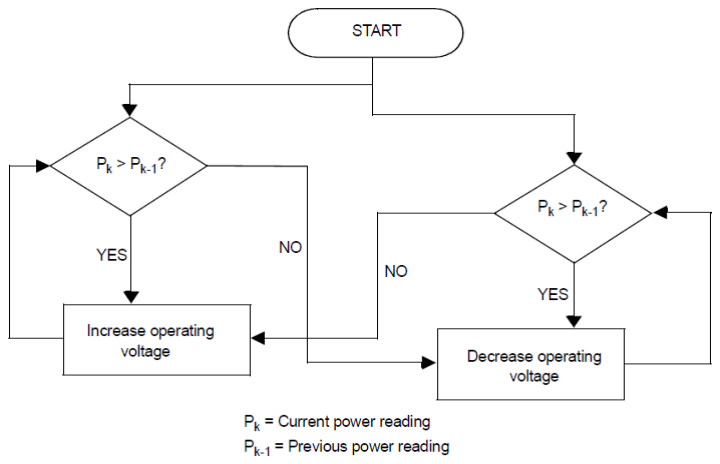
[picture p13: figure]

Fig. 9. Flow Chart of Perturb and Observe Algorithm [1]

2. Mechanical Details
The mechanical aspect of the MPPT began with the following requirements: weatherproofing including water resistance and the ability to withstand high temperatures, protection for the circuit against small impact and rough transportation, and adequate heat dissipation from the circuit to the outside air. A couple of ideas for housing material included printed ABS, purchased injection molding plastic enclosures, purchased extruded aluminum enclosures with outward facing fins, aluminum sheet metal, and purchased ammunition boxes. The choice was made to purchase a NEMA 4 die-cast aluminum enclosure. NEMA 4 is a rating from the National Electrical Manufacturers Association that ensures protection to the user from hazardous part, protection to the enclosure interior from dust, dirt, water, and ice formation. This rating completely fulfills most of the housing design requirements. The purchased enclosure offers the following benefits to the product design:
x The die-cast aluminum is an excellent heat conductor and will dissipate heat from the circuit directly to the outside air.
x The removable lid allows the user access to the circuit for installation and maintenance.
x Mounting holes are available at opposite corners of the box to allow the enclosure to be screwed directly onto a surface.
x A silicon gasket is used that will firmly and durably seal the enclosure with the lid on and tightened.
x Board mounting holes are available inside the box to securely attach a PCB directly to the enclosure.

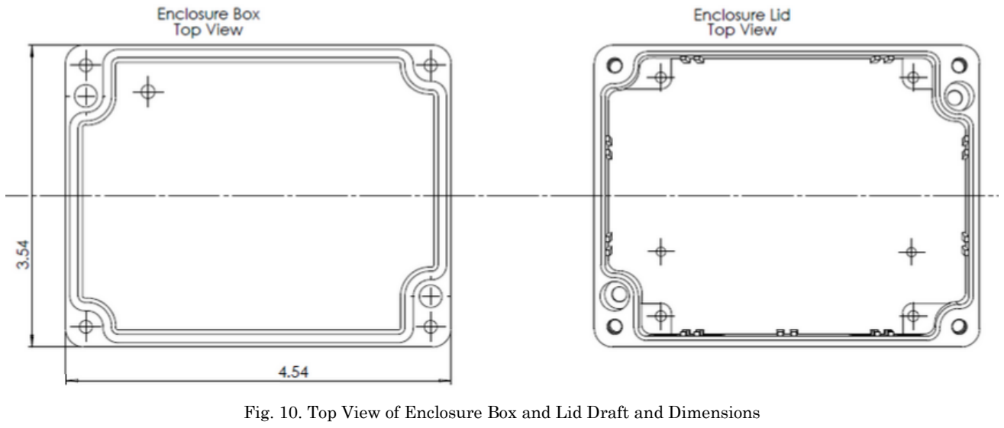
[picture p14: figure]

Fig. 10. Top View of Enclosure Box and Lid Draft and Dimensions

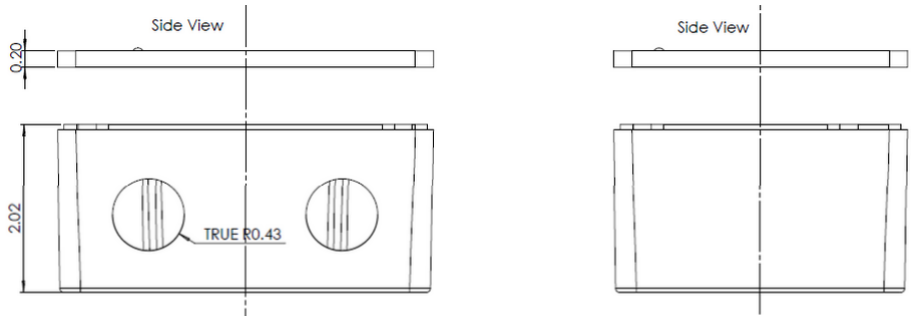
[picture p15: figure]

Drawings and general dimensions for the box and lid are included below in Fig. 10 and Fig. 11.
As shown in Fig. 10 and Fig. 11, additional holes were drilled in the enclosure to fit product needs. Two large holes with a 0.86in diameter were drilled on the side of the box for the use of cable glands. Two small holes were drilled in the bottom of the box for screws to come up and screw into PCB standoffs, securing the PCB to the enclosure. Finally, a small hole was drilled in the lid for an LED circuit function indicator. The PCB is mounted inside of the box with one side screwed into the mounting holes in the box itself. When the enclosure was ordered, there was no expectation of using the mounting platform provided. However, one side of the PCB mounting holes line up almost perfectly with those of the box. A dremel sanding bit was used to widen the holes slightly and then M3.5 x 6mm screws could be used to attach at least half of the PCB to the box. The PCB was not as wide as the enclosure was and did not reach the mounting holes on the other side. Therefore, double side standoffs were used. Initially, aluminum standoffs were used until it was discovered that the PCB mounting holes are very close to the soldering connections for the current sensors and the aluminum would make electrical contact with the circuit. So plastic insulated standoffs were purchased. Screws were used to attach the PCB to the upper half of the standoffs, and then holes were drilled into the bottom of the box as stated earlier and screws came up from the outside of the box into the bottom half of the standoffs. This mounted the PCB at four corners to the enclosure box. Drafts of the standoff and bottom screws are shown below in Fig. 12. Also shown is the heat spreader. This heat spreader was created from a simple 6ft long rolled piece of aluminum purchased at the local hardware store. A small section was cut off and ground flat and smooth to act as a heat spreader between the MOSFET and diode heat sink surfaces and the enclosure box wall. The gap between the heat sink surfaces was large enough that two heat spreaders were required face to face. Thermal grease was used between every face to face contact to minimize air gaps and maximize surface to surface contact and thus heat dissipation.

Fig. 11. Side Views of Enclosure Box and Lid Draft and Dimensions

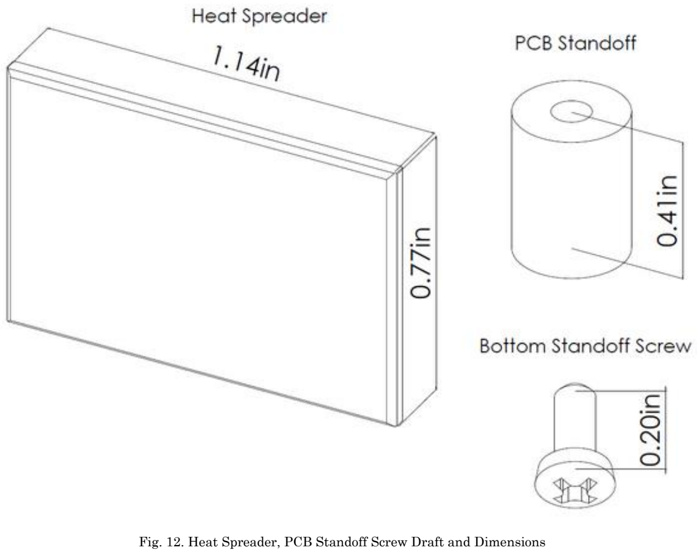
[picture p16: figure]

Input and output cabling between the panel, circuit, and load provided the challenge of figuring out how to make weatherproof and strain relieving cable connections. Cable glands were the solution for both of these requirements. The cable enters the gland body, the rubber washer is placed on the cable gland and butted up against the outside of the enclosure, the lock nut is placed on the gland body thread inside of the box and tightened up against the box wall, and the nut is tightened. Tightening the gland nut clamps a piece of plastic and rubber onto the cable. The plastic grabs the cable for strain relief and the rubber forms a waterproof seal around the cable. The minimum cable size allowed by the cable glands purchased is 0.2in in diameter. This pertains to a 4 AWG cable, not considering insulation. The cable used for testing was 0.21 inches in diameter and sheathed three 20 AWG cables. Drafts for the cable gland components are shown below in Fig. 13 and a rendering is shown in Fig. 14.

Fig. 12. Heat Spreader, PCB Standoff Screw Draft and Dimensions

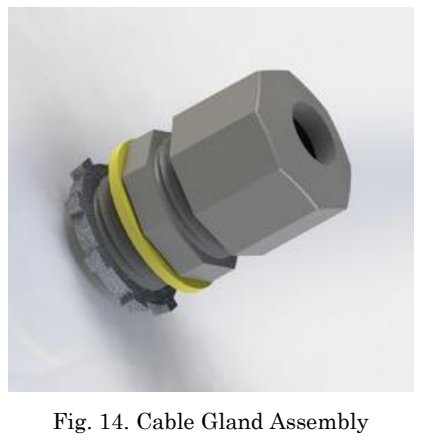
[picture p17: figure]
Fig. 14. Cable Gland Assembly
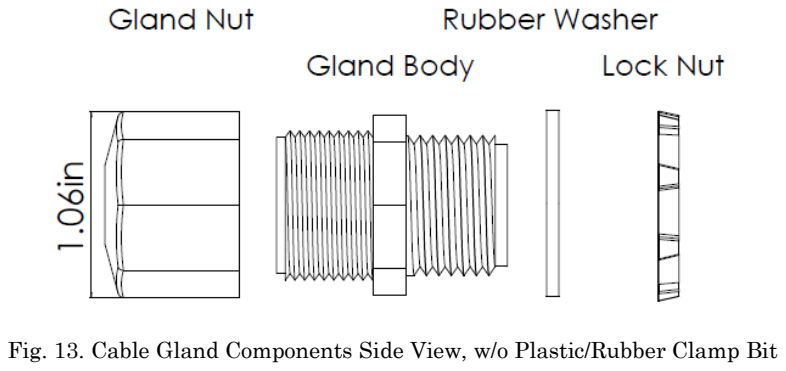
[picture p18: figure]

The printed circuit board and select circuit components were modeled in SolidWorks for use in a final product assembly. This PCB assembly is shown below in Fig. 15. It will be used in final models to indicate the use of heat spreaders, standoffs, and proximity to enclosure walls and cable glands. The MOSFET and diode were chosen to be modeled because they played a crucial role in heat dissipation. The inductors were modeled to indicate the height of the circuit. Finally, the pins were modeled because they were simple to make.
A final assembly is shown below in Fig. 16 and Fig. 17.

Fig. 13. Cable Gland Components Side View, w/o Plastic/Rubber Clamp Bit

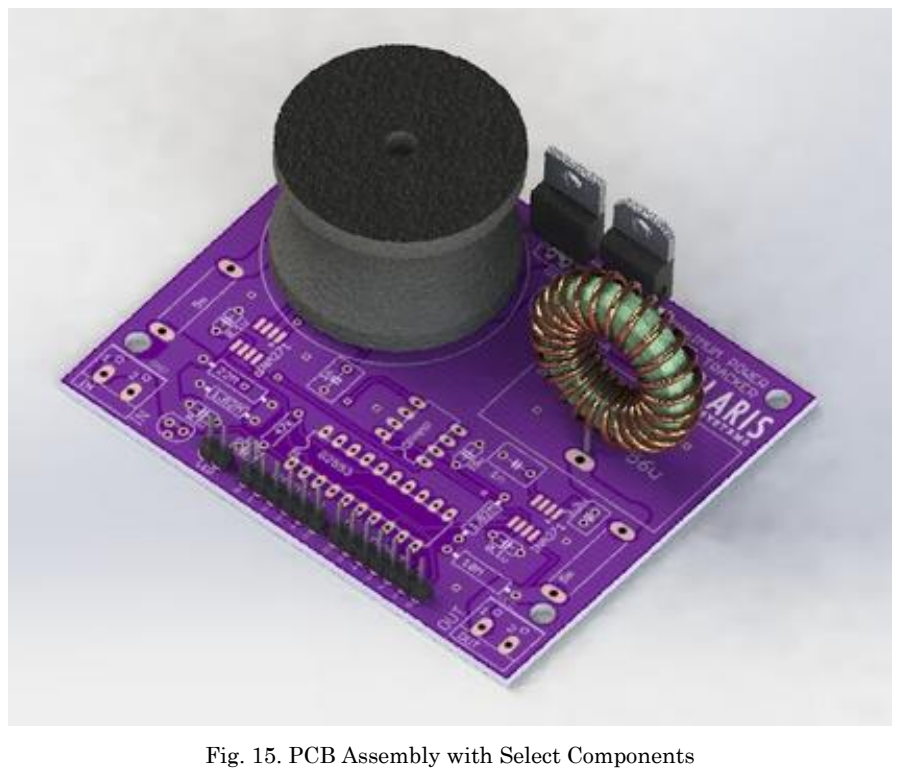
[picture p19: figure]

Fig. 15. PCB Assembly with Select Components

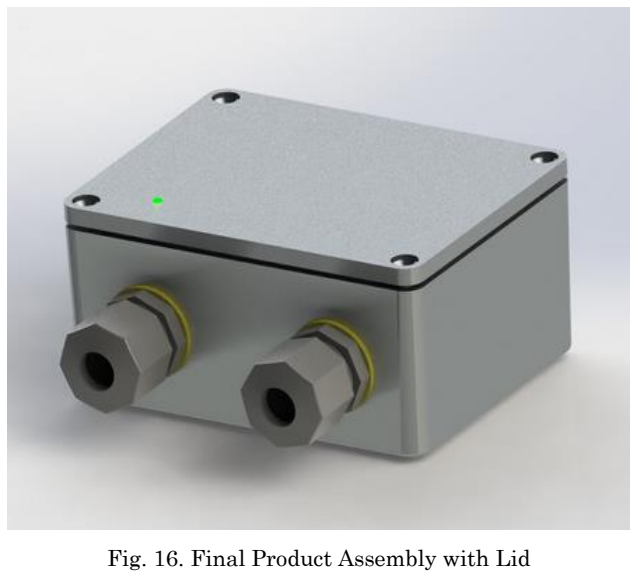
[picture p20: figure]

D. Reliability & Safety (FMECA)

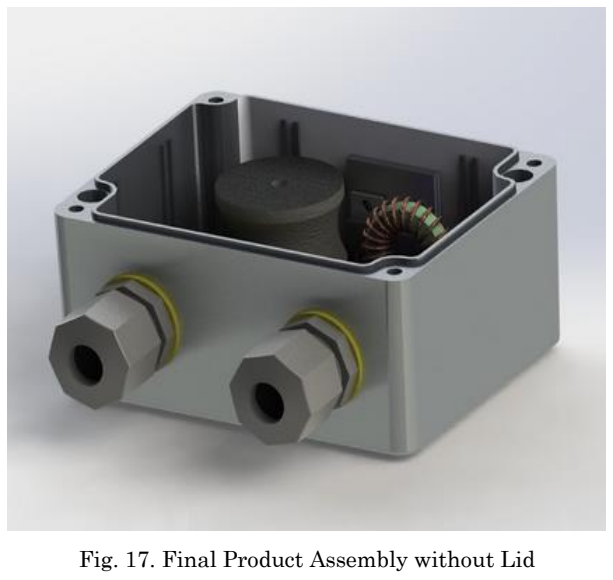
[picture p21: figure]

The FMECA has been divided into seven major items, which account for the major subsystems of the device. For each item, the failure modes were determined, followed by the failure causes, and failure effects. Given these three attributes, a severity index of value 1 to 4 was assigned, 1 being insignificant, 2 being marginal, 3 being critical, and 4 being catastrophic. A probability index of value 1 to 4 was assigned, 1 being extremely remote, 2 being remote, 3 being reasonably probable, and 4 being probable. A third index, criticality, was determined by multiplying the severity and probability indices to give further guidance for ranking potential failures. Given these rankings, control measures were determined to limit the possible failure modes.
i. Current Sensors
Shunt resistors can fail due to a flow of current greater than the specified rating. However, since the resistors have such a low resistance, they are rated for extremely high amounts of current, thus the only likelihood of them failing is due to a physical flaw within the resistor. A physical flaw would cause the resistor to fail, producing an open circuit, thus separating the input from the DC-DC converter. This is not harmful to the PV panel or the DC-DC converter, however, it does result in a non-functioning device, thus a severity of 2 has been assigned. A shunt resistor can also fail by a short circuit due to improper placement or soldering, which causes the microprocessor to be unable to measure the current flowing into the converter. This then affects the power point since it can no longer be tracked by the processor, resulting in an improperly functioning device with unpredictable results. Given these considerations, a severity of 3 and a probability of 1 has been assigned. The most practical way to limit either of these failure modes is to ensure the use of quality sensors.
Fig. 16. Final Product Assembly with Lid | Fig. 17. Final Product Assembly without Lid

ii. | Voltage Sensors
| The voltage sensor is created by two large resistors functioning as a voltage divider, which the analog-to-digital converter can then use to sense the voltage. These resistors can fail open if too much power is supplied to the resistors, causing them to burn out. This would hinder the microprocessor from sensing the voltage, resulting in an improperly functioning device with unpredictable results, thus a severity of 3 and a probability of 1 has been assigned. These resistors can also fail by creating a short circuit to ground, caused by an applied voltage higher than the rating. This would then short the entire panel to ground. This does not harm the panel, however, it does result in a non-functioning device, and thus a severity of 2 and a probability of 1 has been assigned. The most practical way to limit either of these failure modes is to ensure the use of quality sensors.
iii. | DC-DC Converter
| While the DC-DC converter contains numerous components, the MOSFET and diode were concluded to be the most vital when considering failure.
| The MOSFET has two failure modes: open circuit and short circuit. An open failure can be caused by overcurrent or overvoltage from the photovoltaic array and results in no output voltage. A lack of output voltage damages no components or equipment, but results in a non-functioning device, thus a 2 was chosen for severity. A probability of 2 was chosen, as this failure mode is remotely likely to happen given consistent use over a span of time. A closed circuit failure of the MOSFET can be caused by overcurrent and results in the input source being shorted. Shorting a photovoltaic panel results in no damage to the panel, but does result in a non-functioning device, thus a 2 was chosen for severity. A probability of 2 was chosen, as this failure mode is remotely likely to happen given consistent use over a span of time. These failure modes can most practically be limited by ensuring appropriate safety factors in current and voltage for the MOSFET.
| The diode also has failure modes of open circuit and short circuit. A short circuit is caused by overvoltage when the diode is in reverse bias. A short across the diode results in no output voltage. A lack of output voltage damages no components or equipment, but results in a non-functioning device, thus a 2 was chosen for severity. A probability of 2 was chosen, as this failure mode is remotely likely to happen given consistent use over a span of time. An open circuit failure of the diode is caused by continual overvoltage after the diode has reached a short circuit failure. An open across the diode results in no output voltage as well as overvoltage across the other components. This would likely damage the components, leading to a more severe failure. Additionally, this results in a non-functioning device, thus a 4 severity. A probability of 2 was chosen, as this failure mode is remotely likely to happen given consistent use over a span of time. These failure modes can most practically be limited by ensuring the use of a quality diode.
iv. | Microprocessor
| The microprocessor is the brain of the maximum power point tracker. It runs the software which reads inputs from the current and voltage sensors and uses this to adjust the duty cycle of the switched mode DC-DC converter.
| The microprocessor can fail in two ways. The first of these failure modes is lack of power. Three possible causes for lack of power to the microcontroller have been identified. The first of these is that there is an alternative path to ground which is diverting current from the microcontroller and preventing the microcontroller from receiving the necessary voltage. This could be caused by any component failure which shorts the input source, such as a short circuit of the input voltage sense resistor, or a short of the MOSFET. Alternatively, lack of power to the microcontroller could be caused by not having a PV panel attached to the MPPT or voltage input from the panel being below the cutoff of the microcontroller regulator. As there are many causes for this failure mode, a probability of 3 was assigned to this failure mode, signaling that it is fairly likely to happen. However, the severity of failure is a 1, as in most cases lack of power to the microcontroller only happens when the MPPT should not be functioning anyway, and the microcontroller will not be damaged by lack of power. Finally, lack of power to the microcontroller could be caused by failure of the linear voltage regulator. In order to avoid this, a reliable linear regulator will be chosen, also the probability of failure modes which will cause a short of the input panel will be minimized.
| A second failure mode for the microcontroller is power overload. This can result from failure of the linear regulator. The severity of this failure is a 3, since power overload will damage the microcontroller, and possibly destroy it. However, since linear regulators are designed to fail in such a way as to protect the loads they are attached to, this failure mode is very unlikely to occur, so it was given a 1 for probability. This failure mode will be controller by selecting a reliable voltage regulator.
v. Software
| The software for this project is as important as the microcontroller which runs it. Three possible failure modes of the software were identified. The first of these failure modes was variable overflow errors. These errors can occur whenever something is added or subtracted from a variable so that it overflows it allotted number of bits. This can cause errors in software such that variables cannot be accurately read, which can affect the ability of the software to identify the maximum power point. With proper software design, it is unlikely that these errors will occur so a probability of 1 was assigned to this failure mode. If this error does occur, the system may not be able to find the MPP, however lasting damage will not be done, as resetting the microcontroller should solve the problem, thus a severity of 1 was assigned to this failure mode.
A second failure mode of the software will be failure to find the MPP. The primary cause of this type of error will be false peaks as the software searches for the MPP. This is fairly likely to occur as transients from changing the switching duty cycle and changes in weather conditions can cause false peaks in the power calculation, so a probability of 3 was assigned to this failure mode. This is not a very serious failure however, as the software is constantly searching for the MPP and is likely to eventually find the MPP even if false peaks occur. Also, this failure does not cause any permanent damage, and thus is less severe. A severity score of 1 was assigned to the failure to find MPP failure mode. Failure to find the MPP will be mitigated by using a software filter to smooth the power waveform in order to minimize false peaks.
A final failure mode of the software component of this design is a timing error. These errors can occur when interrupts are not properly prioritized or interrupt service routines are too long. This will affect the ability of the circuit to find the MPP and its ability to correctly set the duty cycle of DC-DC converter. These timing errors are fairly likely to occur, as interrupts are somewhat difficult to predict. However, these timing errors do not cause permanent damage and are unlikely to significantly affect the operation of the MPPT, thus a severity score of 1 was given to this failure mode. In order to prevent timing errors, interrupt service routines will be kept as short as possible, and critical interrupts will be given highest precedence. In addition, interrupts will be disabled when time critical code is running.
vi. | Housing & Connectors
| Housing failure can be detrimental to product function. If water or dirt are able to get inside of the housing, the electrical circuit can be severely damaged. Since water is electrically conductive, it is able to significantly affect circuit function. Components can be damaged beyond repair through short circuiting. Failure to protect the circuit can come from housing failure and connector failure. The housing can be built poorly and provide inadequate sealant, can deform from temperature changes coming from both the weather outside and the circuit inside, and can be dropped and mishandled in a way that causes cracks and loses its seal. The connector, connecting the leads from the solar array and the leads that run to the load and/or battery, can open up the circuit to the outside through the inability to seal with varying sizes of leads and improper assembly. For example, though the connector design is not finalized, the preferred design will use a plastic cap that will screw onto a base with a rubber O- ring that clamps onto the wires. If the cap is not screwed on tight enough or the O- ring is broken or missing the connector will fail to seal. The severity of failure to seal was assigned a 3 as the product will fail with enough water contacting the circuit and the user can be shocked if he/she comes into contact with water in contact with the circuit. The probability of failure at this level is low and has placed at a level 1. The housing and connector will be designed with weather resistance as a priority and the probability that they will lose that resistance over time is not high. Extensive testing will be done to ensure adequate resistance.
The housing can also inadequately dissipate heat from the interior. The sun and the circuit will both provide heat to the product, and the housing will need to be provide enough surface area contact with the environment to transfer enough heat to maintain circuit efficiency. This places importance on the material choice and shape of the housing.
The connectors can also fail in not providing enough grip on the cables to keep them connected to the circuit. The leads will experience certain levels of tension and the connectors will have to withstand these forces to keep contact and maintain a seal. A summary of the FMECA can be seen in Table XV below.

Table XV. FMECA Summary
Item | Failure Mode | Failure Causes | Failure Effects | Severity | Probability | Criticality | Control Measures

Current Sensors

Open Circuit | x Overcurrent
x Overvoltage | Short input source | 2 | 1 | 2
Utilize quality Sensors
Short Circuit | x Overcurrent
x Overvoltage | Microprocessor unable
| to monitor current | 3 | 1 | 3

Voltage Sensors

Open Circuit | x Overcurrent x Overvoltage | Microprocessor unable
| | to monitor voltage | 3 | 1 | 3
Utilize quality Sensors
Short Circuit | Overvoltage | Short input source | 2 | 1 | 2

DC-DC
converter

MOSFET

Open Circuit | x Overcurrent
x Overvoltage | No output voltage | 2 | 2 | 4 | Ensure MOSFET safety
factors for both current
and voltage Short Circuit | Overcurrent | Short input source | 2 | 2 | 4

Diode

Open Circuit | Overvoltage | x No output voltage x Overvoltage on other components | 4 | 2 | 8

Utilize high quality diode
Short Circuit | Overvoltage | No output voltage | 2 | 2 | 4

Microprocessor

No Power

x Alternate path to
ground
x No panel connected
x Voltage input below
cut-off
x Failure of voltage
regulator
| | Nonfunctional circuit | 1 | 3 | 3 | x Prevent conditions which short the input x Choosing a reliable voltage regulator
Power Overload | Linear regulator failure | DC-DC circuit failure | 3 | 1 | 3 | Appropriate safety factor

Software

Variable Overflow
Error

Variables such as
characters or integers
are incremented above
their range and
overflow

x Software unable to
correctly read
variables
x Could cause
converter to create
over- or under-voltage conditions.
1 | 1 | 1

Carefully choose variable
types and operations to
ensure that overflow
conditions are avoided

Final Report

Page 31

Failure to Find
Maximum Power
Point

False peak causes
software to choose
wrong maximum power
point

Less than maximum
power extracted from
panel
1 | 3 | 3

Utilize smoothing filters to ensure that the software
does not latch on to small peaks

Timing Error

Improper precedence
causes timing issues
with interrupts

Less than maximum
power extracted from
panel
1 | 2 | 2

Correctly set precedences
for interrupts and keep
interrupt service routines short

Housing

Failure to seal
interior from
weather

x Deformation from
heat
x Mishandling of
product
x Faulty manufacture

x Circuit failure
x Components are
damaged
x Possible shock of
user
3 | 1 | 3 | x Use adequate thermal conductivity in material choice x Exhaustively test for weather resistance

Failure to
adequately cool
interior

x Inadequate
Material
x Inadequate Design

x Circuit efficiency
depletes
x Possible burn of
user
2 | 3 | 6

Connectors

Failure to seal
interior from
weather

x Connection not
assembled correctly
x Inadequate design
for varying lead
sizes

x Circuit failure
x Components
damaged
x Possible shock of
user
3 | 1 | 3 | x Design to be flexible and accommodate varying lead sizes x Design to provide a tight hold on all cables

Failure to
maintain cable
connection

x High tension on
trailing leads
x Inadequate hold on
cables

x Leads are
disconnected from
product
x No output voltage
1 | 3 | 3

E. Prototype Construction & Integration
The process of building this design began with computer models. LTSPICE simulations and SOLIDWORKS models were completed to ensure that the design would function once built. This prevented many problems which could have occurred during the build process. A printed circuit board (PCB) was designed in EAGLE. After the board design was finished the dimensions of the board were used to plan the housing design for the MPPT. Since JBU does not have the capability of printing custom PCBs an outside company was used to manufacture this PCB. While this board was being printed, the components for the board were ordered. Once the PCB and all components for the design had been received, the circuit was assembled by soldering on each component. Surface mount components were soldered first, using solder paste and a heat gun. The through-hole components were then soldered in from shortest to tallest. Upon assembly, the initial idea was to test the circuit to hope that we finished by connecting it to a 65 W panel. This open-circuit voltage of this panel, 92 V, was too high for the linear regulator and caused it to fail, and provide over-voltage to many of the components on the board. When troubleshooting which components had failed, it was noticed that the operational amplifier was not functioning properly. Upon inspection it was found that the EAGLE model of the OP-AMP had the pins labeled in an improper order. In order to correct this a small solderable breadboard called a stamp was created to properly connect the operational amplifier to the circuit. During this analysis it was also brought to light that the resistors used in the original design were too large and caused the OP-AMP to not behave as an ideal OP-AMP. This problem was solved by reducing the resistance of the resistors in our OP-AMP circuit to kilohm range resistors instead of megohm range resistors. While changing these resistors it was determined that the ADC reference voltage should be lowered, so new resistor values were selected to decrease the voltage which was fed into the ADC. The calculations to find these resistor value can be seen in the Technical Analysis section of this report. After making all these changes a new board was assembled since the IC chips on the first board were too difficult to replace. The second board was tested with a voltage source which could supply 44 Volts and 22 Amps. During testing a user error occurred where a voltage of 20 V with 7 A were applied to the circuit. This resulted in a 140 W being transferred through the circuit which exceeded the 100 W rating of the circuit. This caused the circuit to fail, although it was unclear what component or components had failed. Since the cause of this failure could not be determined, it was decide to repair the first circuit instead of continuing to debug the second. New current monitor chips were implemented to the first board. After verifying the current sensors were working, his circuit was tested and found to be functioning correctly. The next step was to make the board independent. This required finding a new linear regulator which could regulate the voltage properly to the standards needed for the MSP430G2553 to operate. A new variable output linear regulator was purchased. This regulator had a different pinout than the original regulator and also required two resistors in order to set its output voltage. A second stamp was designed to integrate these resistors as well as connect the new linear regulator with the board. After verifying that this new linear regulator was functioning correctly. The whole circuit was tested.
Concurrently with the assembly of the circuit, a die-cast aluminum case was purchased to house the circuit. After this case was received two holes were drilled for the cable glands. These glands allow for wires to enter the housing while maintaining a water-tight seal. Two additional holes were drilled in the bottom of the case to allow for mounting screws for the PCB. A final hole was drilled in the top of the case for a small LED indicator light. After all holes had been drilled the case was tested for weather resistance. The interior of the case was then readied for the PCB by grinding down the interior ridges to make a smooth surface for the MOSFET and diode heat sinks to connect to. This smooth surface was important in order to insure maximum thermal conduction.
Once the housing components were ready, assembly began. The components include the enclosure box with holes drilled and one side smoothed, enclosure lid with LED hole drilled, LED soldered with a resistor and wires, two cable glands, PCB, PCB standoffs, two heat spreaders, thermal paste, and screws. The screws used are the four that attach the lid to the box, two that attach the PCB to the box, and two that attach the box to the standoffs. Assembly was done as so:
Thermal paste was applied to one heat spreader and placed firmly against the enclosure box wall. Thermal paste was applied to the second heat spreader and placed firmly against the first. The standoffs were then attached to the two mounting holes not in corners of the PCB. A notch had to be cut out of the plastic standoffs to accommodate current sensor soldering connections. The cables were then attached to the circuit terminals. This was done before placing the circuit into the housing because the circuit terminals were close enough to the cable glands to make attaching cables difficult. A note was made in the future product improvements section. The PCB was lowered into the housing and screwed into the enclosure box on the opposite side of the cable glands with the MOSFET and diode heat sinks facing the smoothed side of the enclosure wall. Screws were inserted into the holes in the bottom of the enclosure box and screwed into the bottom side of the standoffs. Thermal paste was applied to the MOSFET and diode heat sink faces and pressed firmly against the second heat spreader surface. The soldering connections for the MOSFET and diode caused them to pull away from the heat spreader surface at an angle, not allowing for a surface to surface connection. This was solved by adding a small dab of cyanoacrylate glue to the edges of the heat sinks, heat spreaders, and enclosure box wall. A small amount was used to allow for simple disassembly. The cable glands were tightened by holding the cables on the interior with pliers to prevent the cable from twisting as the nut is tightened which would pull on the connections to the circuit terminals. Finally, the LED wires were placed on the appropriate pins and the enclosure lid screwed down with the four corner screws. The LED wires were made to be long enough to not cause hassle when removing and placing the enclosure lid.

F. Testing & Verification
In order to verify that the design would function as designed, the individual subsystems of the design were first tested to ensure that they met specifications. The entire system was then tested to determine if it met the design goals.
The DC-DC converter subsystem was first tested to determine if it was able to vary the voltage output based on the duty cycle. An input of 5 V was applied to the DC-DC converter with duty cycles ranging from 25% to 62.5%. The results of this test can be seen in Table XVI. From the table, it can be seen that the output voltage did vary with the duty cycle as desired. The variation of the measured output voltage from its expected values from the ideal equation
(5) and LTSPICE simulation can be attributed primarily to losses across the diode and MOSFET, as well as losses due to non-ideal components. This variation is not concerning in this design however, since the ideal equation will not be used to estimate the voltage output in this design.

Table XVI. Duty Cycle Testing Results
Vin | Duty Cycle | Ideal | LTSPICE | Measured
5.00 | 25% | -1.67 | -1.38 | -1.06
5.00 | 37.5% | -3.00 | -2.62 | -2.22
5.00 | 50% | -5.00 | -4.53 | 3.91
5.00 | 62.5% | -8.33 | -7.72 | -6.83

The efficiency of the DC-DC converter was then tested. This testing by varying the duty cycle and input voltage of the DC-DC converter and measuring the input power and output power. The efficiency of the circuit was then calculated using equation (13). The results of this test can be seen in Table XVII. From Table XVII it can be seen that the average efficiency of the circuit was 74.61%. This exceeds the efficiency requirement of 70%. In subsequent designs efficiency will be increased. Methods to improve efficiency are discussed in the Future Work section of this report.

| | η = Pout Pin
(13)

Table XVII. Efficiency Testing Data

Duty Cycle

Input Voltage
(V)
| Input Current (A)

Power In

| | (W) | Output
Voltage (V)
| | | | Power Out (W)
Efficiency

30%

5 | 0.13 | 0.65 | 1.65 | 0.45 | 69.46%
10 | 0.29 | 2.9 | 3.57 | 2.11 | 72.88%
12.5 | 0.39 | 4.875 | 4.65 | 3.59 | 73.56%
15 | 0.49 | 7.35 | 5.72 | 5.43 | 73.82%
17.5 | 0.58 | 10.15 | 6.78 | 7.62 | 75.11%

20 | 0.71 | 14.2 | 7.95 | 10.48 | 73.81%
25 | 0.96 | 24 | 10.4 | 17.94 | 74.74%
30 | 1.32 | 39.6 | 13.4 | 29.78 | 75.20%

40%

5 | 0.32 | 1.6 | 2.66 | 1.17 | 73.34%
10 | 0.74 | 7.4 | 5.83 | 5.64 | 76.17%
15 | 1.2 | 18 | 9.12 | 13.79 | 76.63%
20 | 1.77 | 35.4 | 12.85 | 27.38 | 77.35%

50%

5 | 0.71 | 3.55 | 4 | 2.65 | 74.74%
10 | 1.75 | 17.5 | 9 | 13.43 | 76.76%

60%

5 | 1.65 | 8.25 | 6.11 | 6.19 | 75.04%
6 | 2.07 | 12.42 | 7.5 | 9.33 | 75.11%

The sensors subsystem was then tested to insure that the current and voltage sensors could be used to accurately measure current and voltage in and out of the circuit. In order to do this testing, each sensor was evaluated by providing to it a known voltage or current using a DC voltage source and resistors. The output of the sensor was then compared to the reading from a DMM to determine if the output voltage of the sensor was linearly related to the input. The output of each sensor was then read using the MSP430 ADC. Linear regression was then used to relate the ADC values to the actual voltage and current values read by the DMMs. This test is discussed in further detail in the Technical Analysis section of this report. Table XIV. ADC Calibration Data contains the data from this test and equations (9) through
(12) contain the resulting equations for Iin, Vin, Iout, and Vout respectively. Microsoft Excel was used to find the correlation between these equations and the measured values in Table XIV. All correlation coefficients were found to be greater than 0.993, meaning that these equations closely match the measured data.
The housing was first tested for weatherproofing by placing a piece of humidity sensitive paper inside the box then submerging the empty housing in water to a depth of 5 inches. The housing remained underwater for 5 minutes. The housing was then opened and the humidity sensitive paper was examined in order to determine if water had entered the housing. It was determined that no water entered the housing during this test. Since water was not able to enter the case when submerged, it was determined that the case was sufficiently weather proof.
After testing each of the subsystems, the final design was assembled. After assembling the full circuit the self-consumption of the microcontroller and sensors was measured by plugging the circuit into a 65W panel and measuring the current flowing out of the linear regulator using a DMM. Power consumed by the microprocessor and sensors was then calculated by multiplying this current by the voltage output of the linear regulator. The current output of the linear regulator was measured to be 17.5 mA and the voltage out of the regulator was

3.69 V. This yielded a self-consumption of 64 mW, which is 36 mW less than the 100 mW parameter set forth at the beginning of this design process.
The maximum power point tracking functionality of the prototype was then evaluated. This testing was done first using two 15 W Thunderbolt Magnum Solar PV panels located in the JBU Solar Lab. For this test with the MPPT outside its case and thus there was no heat sink for the diodes or MOSFET. The use of the 15 W panel for these tests ensured that the circuit would not be thermally damaged while the case was being completed. For this test, the MPPT with a 6Ω load resistor was connected to one 15 W PV panel while a 6Ω resistor was connected directly to another identical 15 W PV panel. Data for this test was taken using a digital oscilloscope which saved voltage readings every 0.2 seconds. The voltage across each resistor was measured so that power could be calculated using (14). This test was done for 450 seconds, which is the max time for which the oscilloscope can save data. The panels were then swapped and the test was repeated. It was determined from this data that both panels were not in fact identical and that one panel produce significantly more power than the other despite being the same model. This was found to skew the test data. However, since the testing was done on a cloudless day and both tests were run sequentially, it was determined that the MPPT data could be compared to the baseline data from the other trail so that both data sets would be from the same panel.
Data from these tests was then analyzed. From the instantaneous voltages, instantaneous power was calculated using equation (15). Excel was then used to calculate a 10 point moving average of the instantaneous power in order to smooth the instantaneous power curve. Plots of this smoothed instantaneous power curve can be seen in Fig. 18 and Fig. 19. From the figures it can be seen that the MPPT significantly increased the power delivered to the load resistor relative to the baseline test.

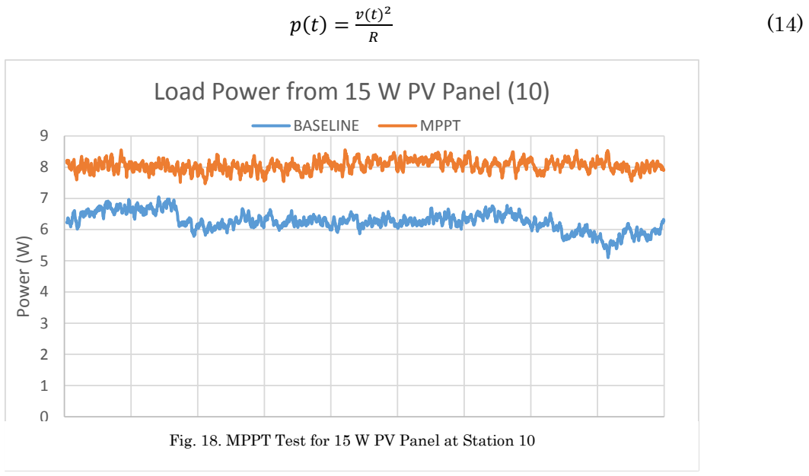
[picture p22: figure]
Power (W); Time (s); Load Power from 15 W PV Panel (9); BASELINE; MPPT; Load Power from 15 W PV Panel (10)

Fig. Fig. 1819. MPPT Test for 15 W PV Panel at Station 10 . MPPT Test for 15 W PV Panel at Station 9

The average power dissipated over the duration of the test was then calculated by first calculating the RMS voltage of each test using equation (15).

VRMS = √¹
N ∑ | v(n) N | 2 n=0 | (15)
The RMS voltage was then used to find average power using (16). These average power values were then compared to determine the percent increase in power using the MPPT using (17). It was found that the percent increase in power for the 15 W panel at station 9 was 41.71% and the percent increase for the panel at station 10 was 28.77%. This gave an average percent increase of 35.24% which is well above the required percent increase of 10% for the design to be considered successful. It is important to note that this percent increase includes the lower than desired efficiency of the DC-DC converter. If this efficiency could be increased, the over percent increase of power would be increased as well.

P = VRMS2
R | (16)

ΔP = PMPPT−PBASE
PBASE
× 100% | (17)

Temperature testing was conducted using the PCB circuit inside of the sealed housing. Two thermocouples were used to read temperature levels as the circuit was given 25 W of power with a roughly constant 2 A input. One thermocouple was placed above the heat spreaders for the MOSFET and diode and the other thermocouple was placed in ambient space above the middle of the circuit. Testing was done over the span of about 60 minutes until the temperature did not significantly change over time. Maximum temperatures of the individual circuit components were found from the data sheets. This indicated a maximum circuit temperature of 185℉. Testing results showed an equilibrium temperature of 120℉ inside of the product, with outside ambient temperature at 77℉ and a 25 W input.
From the tests run on this design it was determine that the circuit met the criteria set forth for it in most categories. Testing showed an average DC-DC converter efficiency of 75% which was 5% higher than the requirement of 70%. The average ΔP for the circuit was 35.24% which exceeded the ΔP requirement of 10% by 25.24%. In addition, self-consumption for the circuit was measured to be 64 mW, which us 36 mW less than the design requirement of 100 mW. Thermal testing showed max temperature of 120°F, which was 65°F less than the requirement of 185°F. Finally, while the initial design called for the circuit to handle up to 100W, the circuit was only tested with up to a 65W panel. While the component specifications should allow for 100W, the circuit can only be verified up to 65W.

IV. SCHEDULE & MODIFICATIONS
The schedule was originally broken down into four pieces: research, design/troubleshoot, assembly, and testing of the prototype; however this overlooked documentation, manuals, and other written portions of the design process. This documentation was added to the length of time required to complete task. Most of the schedule elements overlapped with another, however there were certain tasks such as programming and troubleshooting which depended on the completion of other tasks before they could be started. The completion of prior tasks such as troubleshooting for all the components led to delays that could only begin once the initial problem was solved. To begin the process of making an MPPT, the first step was to have time to research how an MPPT works, along with reading articles on DC-DC converters used in MPPT applications. This took a significant portion of time since there were other assignments for junior design during this research phase. The design portion included the printed circuit board (PCB) along with the housing of the MPPT. Some mistakes were made with components selection and PCB layout which led to a significant amount of time spent troubleshooting. There were not as many problems with the mechanical side of the MPPT. The housing components were not all gathered until late in the semester. Extensive planning was done for choosing which components to use, but acquiring them so late left little to no room for major revisions if major revisions became necessary. Thankfully, all the components functioned as expected and provided a waterproof enclosure interior that dissipated circuit heat at a reasonable rate. The original plan left more time for testing than was done. Extensive temperature testing would be ideal for a wide variety of input wattage. The assembly phase is where the final PCB and the mechanical housing come together to create the final MPPT. The testing phase is to show data for the final presentation and to verify that the prototype meets all the requirements. This was the final step after assembly. Overall the timeline did not change significantly over the course of the semester. Events were lengthened and shortened with respect to one another, but there was not too much added to the timeline. The timeline can be seen in Fig. 20 below.

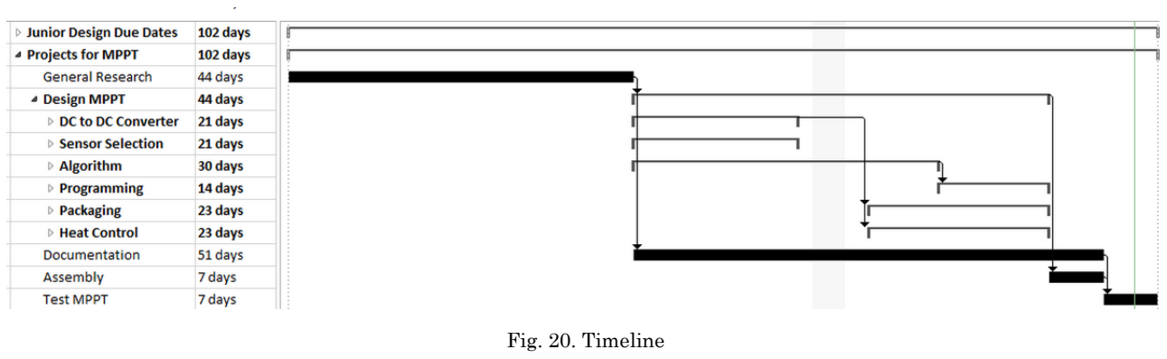
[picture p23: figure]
Fig. 20. Timeline

V. FINAL BUDGET & FUTURE PRODUCTION COSTS
The final budget from the project can be seen in Table XVIII. As shown, we remained well within our budget, having an excess of approximately $550 upon project completion. The vast majority of expenses were in electrical components, as expected.

Table XVIII. Budget
Date | Payee | Category | Description | Inflow | Outflow Balance
Balance Forward | 0.00
1/14/2015 Junior Design Team 1 | Income | Junior Design Budget | 150.00 | 150.00
1/14/2015 Junior Design Team 1 | Income | SURF Grant | 600.00 | 750.00
3/20/2015 Digi-Key | Electrical | PCB Components for 3 Boards | 93.00 | 657.00
3/20/2015 Digi-Key | Shipping | PCB Components for 3 Boards | 7.17 | 649.83
3/20/2015 OSH Park | Electrical | 3 Printed Circuit Boards | 43.85 | 605.98
4/16/2015 Lowe's | Housing | Aluminum and silicone caulk | 14.93 | 591.05
4/16/2015 RadioShack | Housing | Rubber insulated standoffs | 3.44 | 587.61
4/16/2015 Protocol Computer Services Housing | Thermal compound | 8.75 | 578.86
4/18/2015 Amazon.com | Housing | Waterproof aluminum box | 13.09 | 565.77
4/27/2015 Amazon.com | Electrical | 2 Chassis-Mounted 6 Ohm Resistrs | 9.17 | 556.60
4/30/2015 Amazon.com | Packaging Cardboard box | 5.38 | 551.22
5/1/2015 | RadioShack | Electrical | Linear regulator | 3.99 | 547.23

The Bill of Materials is shown in Table XIX. Two important constraints set at the beginning of the project were that prototyping cost must not exceed $150 and production cost must not exceed $75. As shown, the prototyping cost for a single board was $87.21, well within the constraint set. The production cost for a 1000-unit run was calculated to be $40.71, also well within the constraint set.

Table XIX. Bill of Materials
PROTOTYPE | PRODUCTION
QTY CATEGORY | DESCRIPTION | MAN | MAN P/N | Unit Cost | Cost | Unit Cost | Cost
1 | DC-DC Converter | 120 µH Fixed Inductor | Bourns Inc. | 1140-121K-RC | $7.65 | $7.65 | $5.65 | $5.65
1 | DC-DC Converter | 56 µH Fixed Inductor | Bourns Inc. | 2310-V-RC | $3.19 | $3.19 | $1.77 | $1.77
1 | DC-DC Converter | 27 µF Aluminum-Polymer Capacitor | Nichicon | PLV1J270MDL1TD | $2.53 | $2.53 | $1.29 | $1.29
1 | DC-DC Converter | 3.3 µF Ceramic Capacitor | TDK Corporation | FK16X7R1E335K | $0.45 | $0.45 | $0.13 | $0.13
1 | DC-DC Converter | Schottky Diode | STMicroelectronics | STPS10L60D | $1.78 | $1.78 | $0.53 | $0.53
1 | DC-DC Converter | N-Channel MOSFET | NXP Semiconductors | BUK6507-75C,127 | $2.05 | $2.05 | $0.96 | $0.96
1 | DC-DC Converter | 4 Position Terminal Block | On Shore Technology | OSTTC040162 | $0.79 | $0.79 | $0.41 | $0.41
2 | Sensors | 5 mΩ Current Sensing Resistor | Stackpole Electronics Inc. | BR3FB5L00 | $0.87 | $1.74 | $0.31 | $0.62
1 | Sensors | 470kΩ Resistor | Stackpole Electronics Inc. | CF18JT470K | $0.10 | $0.10 | $0.01 | $0.01
1 | Sensors | 11kΩ Resistor | Yageo | CFR-50JB-52-11K | $0.10 | $0.10 | $0.01 | $0.01
1 | Sensors | 47kΩ Resistor | Yageo | CFR-50JB-52-47K | $0.10 | $0.10 | $0.01 | $0.01
1 | Sensors | 1.1kΩ Resistor | Yageo | CFR-50JB-52-1K1 | $0.10 | $0.10 | $0.01 | $0.01
1 | Controller | IC MCU 16BIT 16KB FLASH 20DIP | Texas Instruments | MSP430G2553IN20 | $2.80 | $2.80 | $1.40 | $1.40
1 | Controller | IC REG LDO 3.3V 0.8A TO220AB | STMicroelectronics | LD1117V33 | $0.62 | $0.62 | $0.21 | $0.21
3 | Controller, Sensors | 0.1 µF Ceramic Capacitor | Kemet | C410C104M5U5TA7200 $0.25 | $0.75 | $0.06 | $0.19
1 | Controller | 10 µF Ceramic Capacitor | TDK Corporation | FK18X5R0J106M | $0.40 | $0.40 | $0.11 | $0.11
1 | Controller | 47 kΩ Resistor | Vishay BC Components | PR01000104702JR500 | $0.37 | $0.37 | $0.05 | $0.05
1 | Controller | 20 Pin DIP Socket | On Shore Technology | ED20DT | $0.26 | $0.26 | $0.12 | $0.12
2 | Sensors | Current Shunt Monitor | Texas Instruments | INA271AIDR | $2.44 | $4.88 | $1.01 | $2.03
2 | Sensors | 1 nF Ceramic Capacitor | Vishay BC Components | S102K29Y5PN63J5R | $0.25 | $0.50 | $0.05 | $0.10
1 | Indication | 3mm Green LED | Lite-On Inc. | LTL-4236N | $0.33 | $0.33 | $0.06 | $0.06
6 | Indication | 120 ohm Resistor | Stackpole Electronics Inc. | RNMF14TC120R | $0.14 | $0.84 | $0.01 | $0.09
1 | Sensors | IC OPAMP GP 30MHZ RRO 8DIP | Linear Technology | LT1630CN8#PBF | $6.53 | $6.53 | $3.27 | $3.27
3 | Sensors | IC MCU 16BIT 16KB FLASH 8DIP | Assmann WSW Components A08-IC-TT | $0.18 | $0.54 | $0.09 | $0.27
1 | Sensors | 15uF Capacitor | TDK Corporation | FK24X5R0J156M | $0.45 | $0.45 | $0.13 | $0.13

Final Report

Page 41

1 | Header Pins | 20 Pin Headers | Harwin Inc | M20-9992046 | $0.62 | $0.62 | $0.32 | $0.32
1 | Packaging | Duck Brand Self-Locking Mailing Box | Duck | 1062959 | $5.38 | $5.38 | $1.26 | $1.26
1 | Housing | BOX ALUM 4.53X3.54X2.17" NAT | Bud Industries | AN-1304 | $13.09 | $13.09 | $8.91 | $8.91
4 | Housing | Cable Glands | Arlington | LPCG50 | $2.11 | $8.44 | $1.86 | $7.44
4 | Housing | Rubber insulated standoffs | | | $0.89 | $3.56 | $0.02 | $0.08
1 | Housing | 1/16 in. thick, 1 in. wide aluminum | | | $0.15 | $0.15 | $0.05 | $0.05
1 | Housing | Thermal Compound #5 | Arctic Silver, Inc. | | $1.25 | $1.25 | $0.25 | $0.25
1 | Housing | Clear Silicone Caulk | | | $0.25 | $0.25 | $0.05 | $0.05
1 | PCB | Printed Circuit Board | Oshpark.com | | $14.62 | $14.62 | $2.92 | $2.92

VI. FUTURE WORK IMPROVEMENTS
While this prototype met most of the design requirements which were laid out for it, there are areas where the design could improve. The primary way in which this design could be improved is by increasing the efficiency of the DC-DC converter. Initially the design parameters called for an efficiency of at least 85%. It was found that this parameter was unrealistic for an initial prototype, however for future designs the efficiency of the converter could be boosted by replacing the diode in the Ćuk converter with a second MOSFET, adding a snubber circuit in parallel with each of the MOSFETs, and decreasing the switching frequency of the circuit. By replacing the diode with a MOSFET, the voltage drop across this switch will be significantly reduced and thus decrease the power dissipated by this switch for the same current. Adding a snubber circuit across the MOSFETs would also increase efficiency by reducing the overlap of the current and voltage waveforms at switch transitions which reduces the power dissipated by the switch. Finally, decreasing the switching frequency will decrease the number switch transitions, thus reducing the power losses which result in each transition. Reducing the switching frequency will also allow for more duty cycle steps which will allow for finer resolution in determining the maximum power point of the PV panel.
In addition to increasing the efficiency of the DC-DC converter and increasing the resolution of the MPPT, increasing the power rating of the MPPT is of prime concern. While a 65W MPPT was a good prototype and proof of concept, increasing the power rating of the MPPT will make it a more useful product for users. In order to increase the power rating components with higher current and voltage ratings will need to be used as well as a PCB which can handle more current.
The improvements to the housing would all pertain to ease of use. The PCB can be designed for a specific enclosure where the mounting holes line up with enclosure mounting. The enclosure, though it comes from a large distributor at a cheap price, could be a little bit larger to allow input and output cables to be easily attached to the circuit terminals. Different circuit terminals could also be used in the circuit that allow for wider holes and easier clamping onto cables. Additionally, smaller cable glands that are able to waterproof and clamp 2mm diameter cables within a decent margin should replace the ones currently being used. This does not bring up the issue of whether or not the input cable will be two DC cables in power transmission or two DC cables separately. A solution for this includes offering two different models: one with two cable glands and one with four cables glands. Finally, the side of the enclosure which dissipates heat from the MOSFET and diode should be ground evenly to provide a flat surface for the heat spreader to attach to. The method used on the current model involved a dremel tool with a sanding bit and left a bumpy surface. The thermal grease filled in the rough and bumpy surface, but a lot was required to do so. All in all, the flatter the plane between surfaces, the easier it is for heat to flow from one to the other.

Finally, in order to verify the power rating of the MPPT, additional testing should be done with panels with power ratings higher than 15W. This testing was not able prior to publication date due to time restraints and weather patterns.

VII. CONCLUSIONS
In conclusion, this design processes has resulted in an affordable and functional maximum power point tracker which has been tested with PV panels with ratings as high at 65W. The MPPT has been verified to increase the power output to a resistive load by an average of 35.24%. The MPPT design includes an custom Ćuk converter with an efficiency of approximately 75%, and a custom designed printed circuit board which is rated to handle up to 10 A of current. The MPPT uses the Perturb and Observe algorithm to find and track the maximum power point of the PV panel. Additionally, the MPPT is housed within a die-cast aluminum case which is weather resistant and robust. This housing also provides the circuit with excellent thermal performance and is able to keep the circuit below its maximum temperature rating of 185 ℉. All of these features were accomplished for a prototyping cost of $87.21 and an anticipated production cost of $40.71 for a run of 1000 units.
Overall this design exceeded expectations and met both the technical and financial requirements which were placed on it. The design is however still in the prototype stage. Areas for improvement for this design include increasing the efficiency of the DC-DC converter, decreasing the switching frequency, increasing the power rating of the design, and replacing expensive components such as the OP-AMP and linear regulator with cheaper alternatives.

VIII. REFLECTION
In reflecting on this design process, it is first interesting to note the best and worst aspects of our design process. The best design practices that our team developed were detailed research, debugging and problem solving skills, and flexibility. At the beginning of the the design process our team began with lengthy period of research. This research allowed us to understand the inner workings of maximum power point trackers and DC-DC converters, as well as tips for best practices when designing current and voltage sensors. This research allowed us to create a well working design on our first try by learning from the experience and mistakes of others. Our team also developed important debugging and problem solving skills through this project. While our design was very good, it was not perfect, and debugging was necessary. Circuit debugging can be a long and arduous task, but our team work tirelessly to identify issues and find creative solutions. This brings us to the last skill that our team excelled at in this design which is flexibility. When problems arose in the design the team did not just give up, but instead was flexible and willing to change the design in order to improve it. This is extremely evident in the stamps which were created to fix issues with the original PCB. The next time that we are asked to solve a problem, these are skills and habits that we will implement again.
Our team was not perfect however, and many issues kept this design from being as good as it could be. One of this issues was communication, especially between the electrical and mechanical sides of this project. There was a tendency in our team for the Electrical Engineers to work on the electrical part of the design and not communicate effectively with the Mechanical Engineer, and vice versa. Procrastination was another issue which held back this team. While the team began this project strong and was able to get a working prototype early, procrastination on some key elements including testing, housing, and documentation led to a time crunch in the last few days of the project. The next time we are asked to solve a problem this are issue which we will work to resolve.
It is next interesting to reflect on the positive and negative parts our our design. The overall design was excellent and met or exceeded nearly all the requirements placed on it. One of the positive aspects of the design was the DC-DC convert. This subsystem exceeded expectations in both efficiency and performance. The success of this subsystem was primarily do to the time which went into selecting the design and components for the DC-DC converter. This process included extensive simulations and calculations, as well a sizeable amount of time spent selecting components to meet the required specifications while keeping costs low. The most negative part of the design was the errors made in the printed circuit board. These errors required the creation of stamps which connected the pins of the integrated circuits to the correct holes in the PCB. These error were made because of procrastination primarily. Too much time was spent researching, which resulted in a rush to submit the PCB design before spring break. This did not leave our team enough time to triple check everything on the board.
From the processes our team has learned that with hard work and a great education anything is possible. We have learned the importance of sharing responsibility and relying on another. We have also learned to identify each other’s strengths and assign task based on those strengths. Finally, we have learned how to work in an interdisciplinary team to accomplish a task which could not be done by only Electrical Engineers or only Mechanical Engineers.

APPENDIX A

#include <msp430.h>

#include <stdio.h>

//definitions

#define step_size 1

#define PWM_freq 160 | //set frequency to 100 kHz

#define TOP_DUTY 128 | //set max duty cycle to 80%

#define BOTTOM_DUTY 32 | //set min duty cycle to 20%

#define MAX_CURR 5.0 | //set max curr to 5 A

#define DELAY 15 | // 0.5*(12000/4)

#define TIMER_ON | TA1CTL=TASSEL_1+MC_1+ID_2 // use ACLK, timer on, divide by 4

#define TIMER_OFF | TA1CTL=TASSEL_1+MC_0+ID_2 // use ACLK, timer off, divide by 4

// Global Variables
unsigned int adc[32][4] = {0}; | //array to store adc values
float curr_in = 0; | //variable to store current in
float volt_in = 0; | //variable to store voltage in
float curr_out = 0; | //variable to store current out
float volt_out = 0; | //variable to store voltage out
unsigned int duty_cycle = 80; | //variable to store duty cycle, default to 50%
typedef enum {inc, dec} direction; | //enumeration to handle increasing and decreasing
//state for P&O algorithm
direction dir = inc;
unsigned char updown = 1; | // 0 is down, 1 is up
volatile float vo = 0;
volatile float io = 0;
volatile float po = 0;

//Function Prototypes
void Setup_MSP(void); | // Setup watchdog timer, clockc, ADC ports
void Setup_ADC(void); | // Setup input channels and sequences,
void Setup_PWM(void); | // Setup output pin, PWM freq, initial duty cycle,
// PWM mode, and clock setup
void Read_ADC(void); | // This function reads the ADC and stores values
void PandO(void); | // function which adjusts duty cycle via the Perturb
// and Observe Algorithm

int main(void)

{
Setup_MSP(); | //settings for the MSP in general
Setup_ADC(); | //settings for ADC
Setup_PWM(); | //settings for PWM
while (1)
{
Read_ADC(); | //read values from ADC
PandO(); | //update duty cycle as needed using P&O algorithm
}
}

void Setup_MSP(void)
{
WDTCTL = WDTPW + WDTHOLD; | // Stop WDT
BCSCTL1 = CALBC1_16MHZ; | // Set range
DCOCTL = CALDCO_16MHZ; | // Set DCO step and modulation
__enable_interrupt(); | // enable all interrupts
}

void Setup_ADC(void)
{
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

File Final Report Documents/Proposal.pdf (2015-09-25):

John Brown University

PROPOSAL FOR

## Development of a Low-Cost Maximum Power Point Tracker for Low-Wattage Photovoltaic Systems

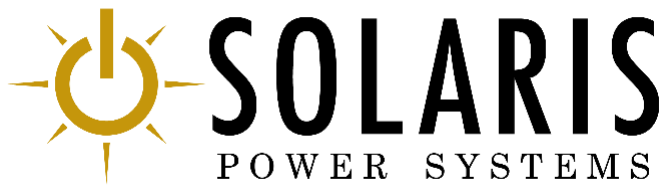
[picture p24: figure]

Kyle Crouse, Zach Lee, Austin Ricks, Zeke Zumbro

Professor Kim Cornett

February 19, 2015

February 19, 2015
Project Proposal

TABLE OF CONTENTS

I. INTRODUCTION

Photovoltaic (PV) systems are an increasingly popular source of power today, as they can be completely independent of an electrical grid, produce no emissions, and require only the sun as a fuel source. These advantages also make PV systems a viable way to alleviate energy poverty in the developing world. However, those lacking access to a reliable energy are often prohibited by the initial cost required by such PV systems. The use of a maximum power point tracker (MPPT) for PV panels can decrease this initial cost
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

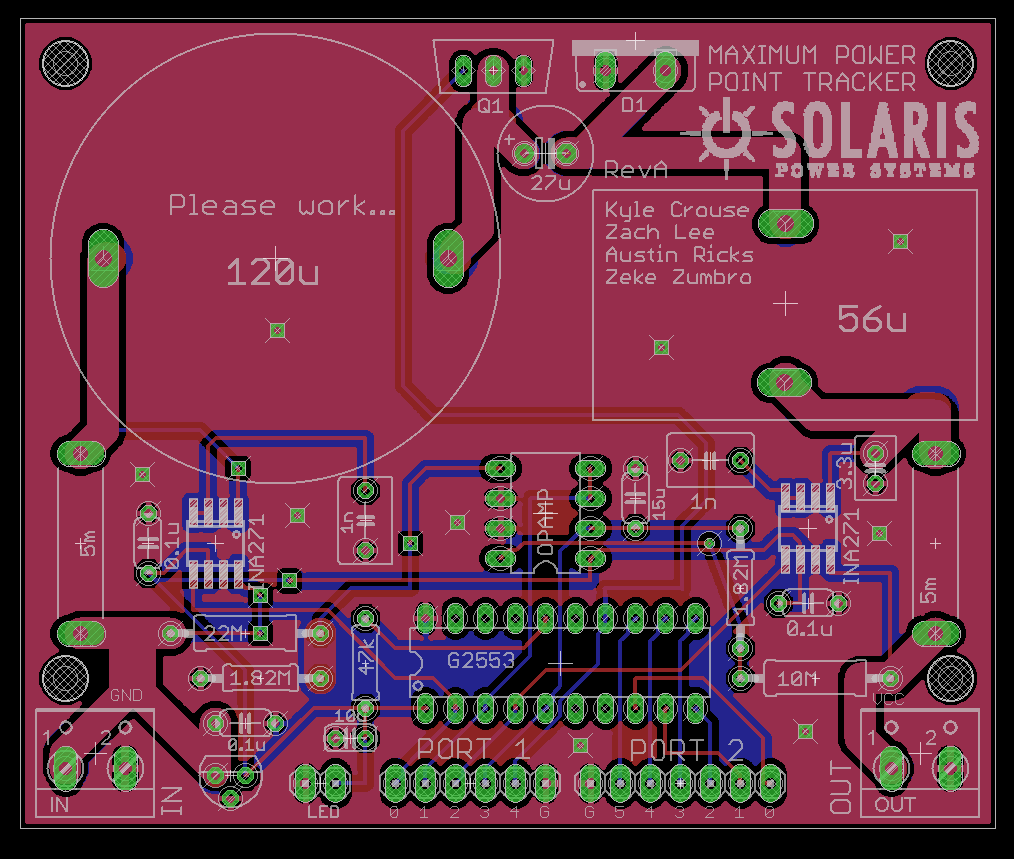
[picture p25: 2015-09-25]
Electrical Hardware/Board.tif

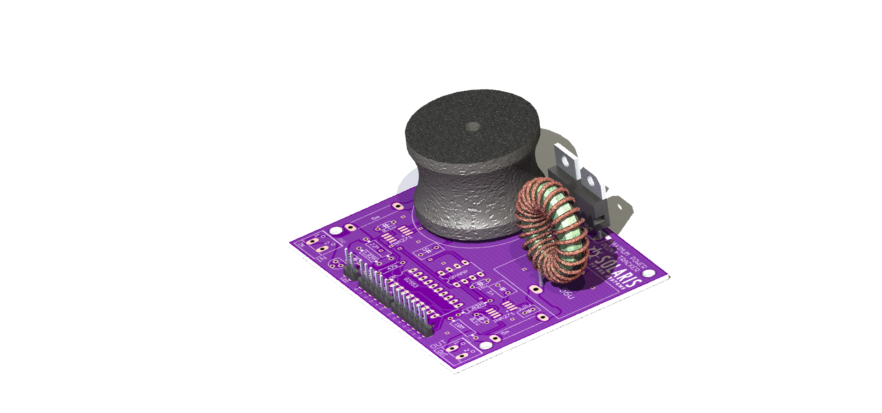
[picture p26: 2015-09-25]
Mechanical Hardware/PCB3.png

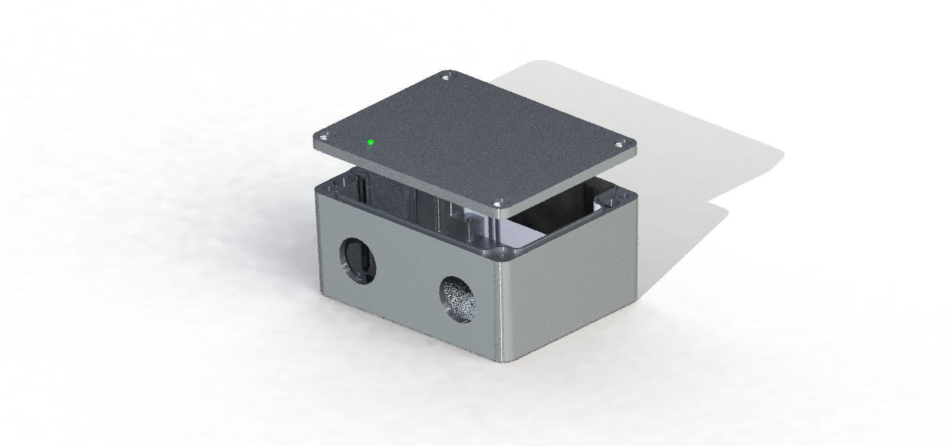
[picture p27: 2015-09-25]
Mechanical Hardware/enclosure.png

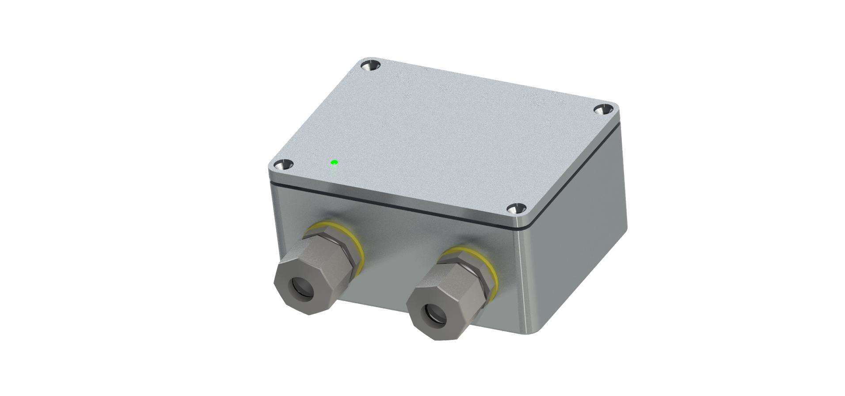
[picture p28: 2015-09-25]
Mechanical Hardware/MKIwithLid.png

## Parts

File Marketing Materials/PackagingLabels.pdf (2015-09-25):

# SOLARIS

POWER SYSTEMS

# MAXIMUM POWER POINT TRACKER

# MKI

## harness the full potential of the sun

# MAXIMUM POWER

# POINT TRACKERMKI

# SOLARIS

# POWER SYSTEMS

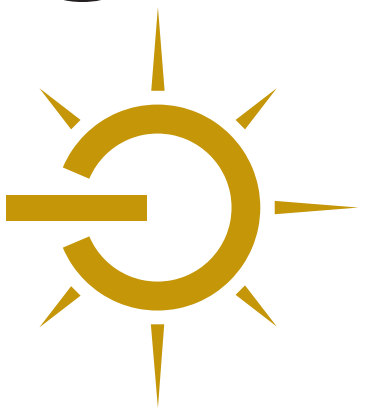
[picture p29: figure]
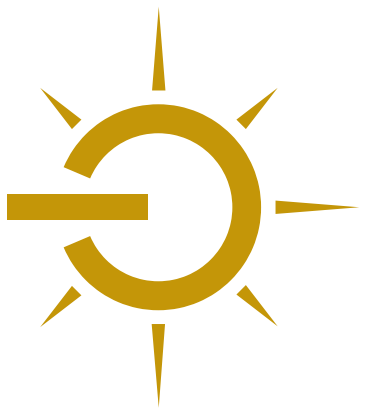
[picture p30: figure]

# MAXIMUM POWER POINT TRACKERMKI

### Features:

- Increase the power output of your 100 W solar panel!
- Plug & play. Minimal set up necessary!
- Compact. Takes up almost no space at all!
- Durable. Withstands the toughest of weather conditions!
- Mountable. Designed to interface with several mounting configurations!

by SOLARIS POWER SYSTEMS

## MAXIMUM POWER POINT TRACKERMKI

### Specifications:

- Max Power Rating: 100 W
- Max Voltage Input Rating: 20 V
- Max Voltage output: 25 V
- Designed for a resistive load.
- Not intended for batteries.

by SOLARIS POWER SYSTEMS

### WARNING:

This device is designed
for high power applications. Please do not attempt to
install or operate unless
you are qualified to do so.

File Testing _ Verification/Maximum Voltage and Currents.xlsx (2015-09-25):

L1 | Good | L2 | Good | D | Good | C1 | Good | C2 | Good | M1
Voltage | Current | Voltage | Current | Voltage | Current | Voltage | Current | Voltage | Current | Voltage | Current
-16 V | 8 A | 21 V | 3 A | 20 V | 10 A | 20 V | 9 A | 20 V | ~0.5 A | 27 V | 10 A
Component | Max Voltage | Max Current
L1 | 16 V | 8 A
L2 | 21 V | 3 A
D | 20 V | 10 A
C1 | 20 V | 9 A
C2 | 20 V | ~0.5 A
M1 | 27 V | 10 A

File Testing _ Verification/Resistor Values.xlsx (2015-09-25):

Voltage Sensor Resistor Selection
Map 64 V to 1.5 V
0.0234375
 | Ideal | Actual | R2/R1
R1 | 470k | 470600 | 2.34E-02 | 2.29E-02
R2 | 11k | 11010 | 0.00E+00
R3 | 47k | 46370 | 2.36E-02
R4 | 1.1k | 1095 | 0.00E+00 | 2.31E-02

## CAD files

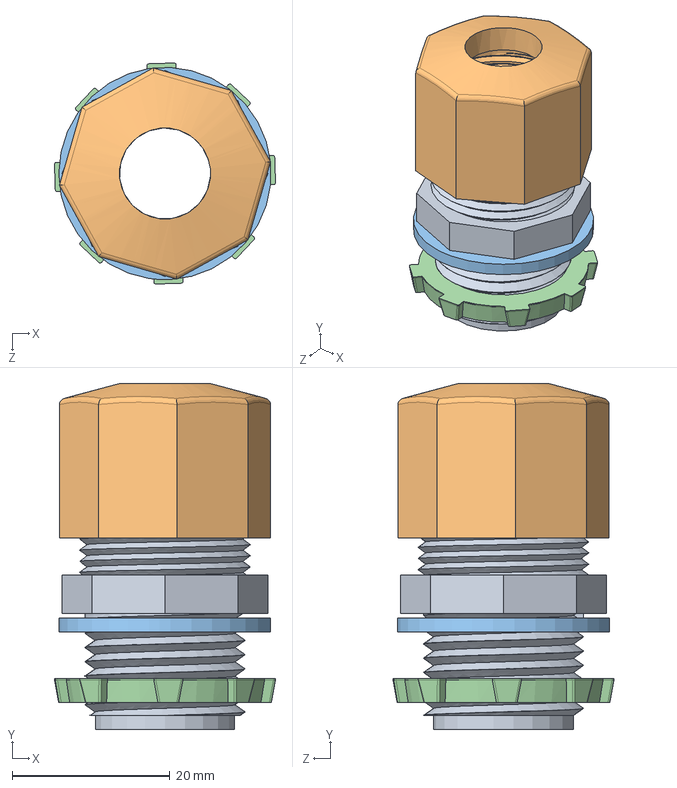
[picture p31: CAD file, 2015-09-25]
Mechanical Hardware/CableGland/Gland.SLDASM
28.0 x 43.9 x 28.0 mm
GlandBodyWithThread
GlandNutWithThread
GlandRubberWasher
GlandLockNutWithThread

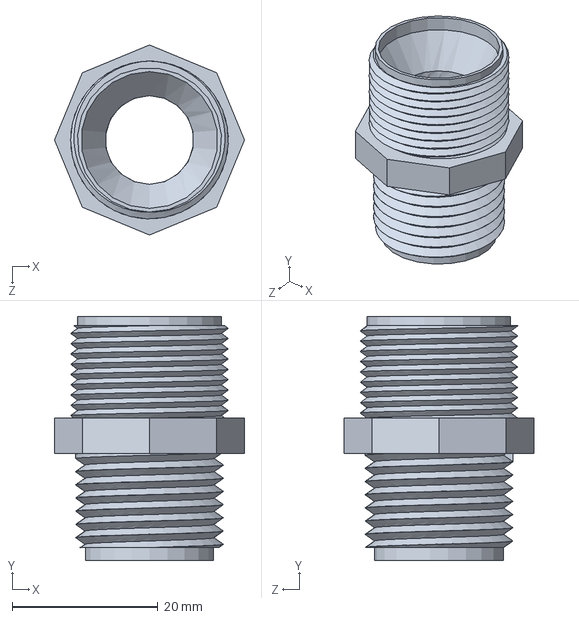
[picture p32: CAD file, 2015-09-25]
Mechanical Hardware/CableGland/GlandBodyWithThread.SLDPRT
26.1 x 33.5 x 26.1 mm

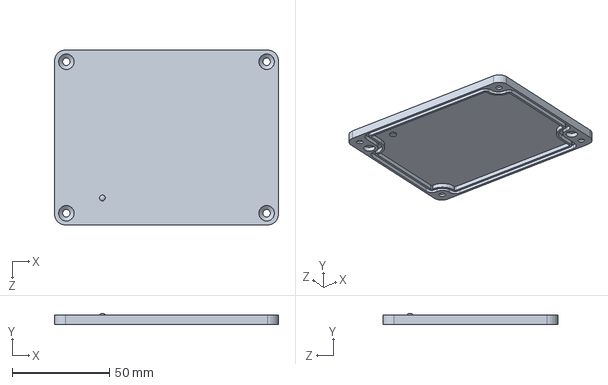
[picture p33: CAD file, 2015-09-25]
Mechanical Hardware/Enclosure/LidFinal.SLDPRT
115.2 x 5.84 x 90.0 mm

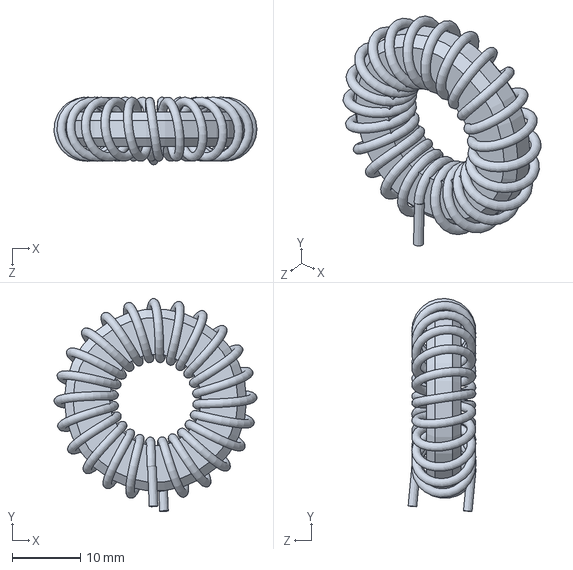
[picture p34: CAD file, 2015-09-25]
Mechanical Hardware/PCB/PCBInductor2.SLDPRT
29.7 x 31.2 x 9.92 mm

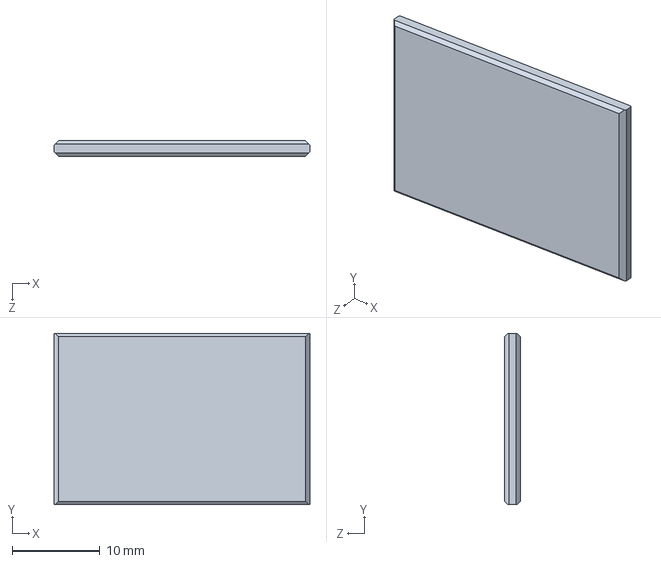
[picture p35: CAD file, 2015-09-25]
Mechanical Hardware/VariousComponents/HeatSpreader.SLDPRT
29.2 x 19.6 x 1.78 mm

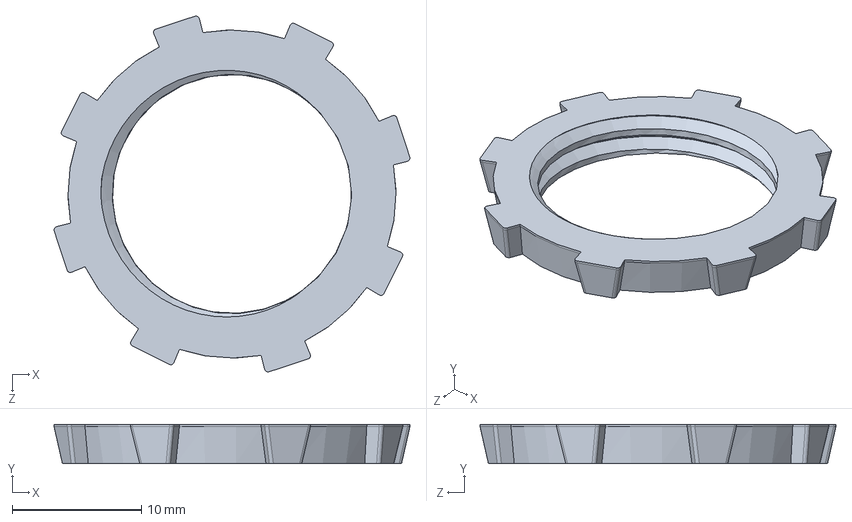
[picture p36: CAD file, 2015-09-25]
Mechanical Hardware/CableGland/GlandLockNutWithThread.SLDPRT
27.6 x 3.05 x 27.6 mm

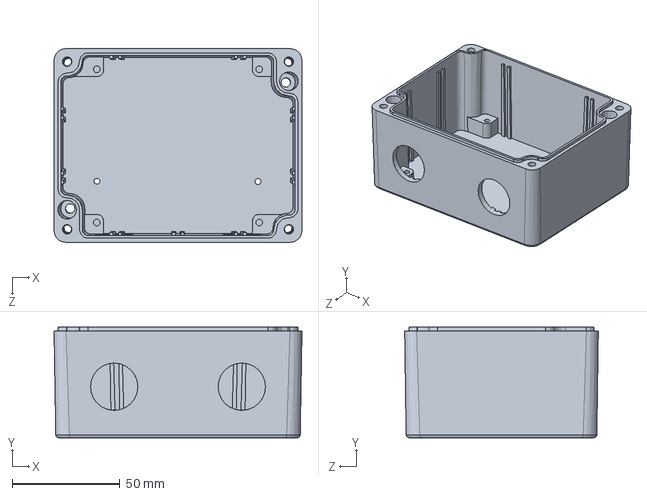
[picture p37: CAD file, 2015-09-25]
Mechanical Hardware/Enclosure/BoxFinal.SLDPRT
115.1 x 51.3 x 89.9 mm

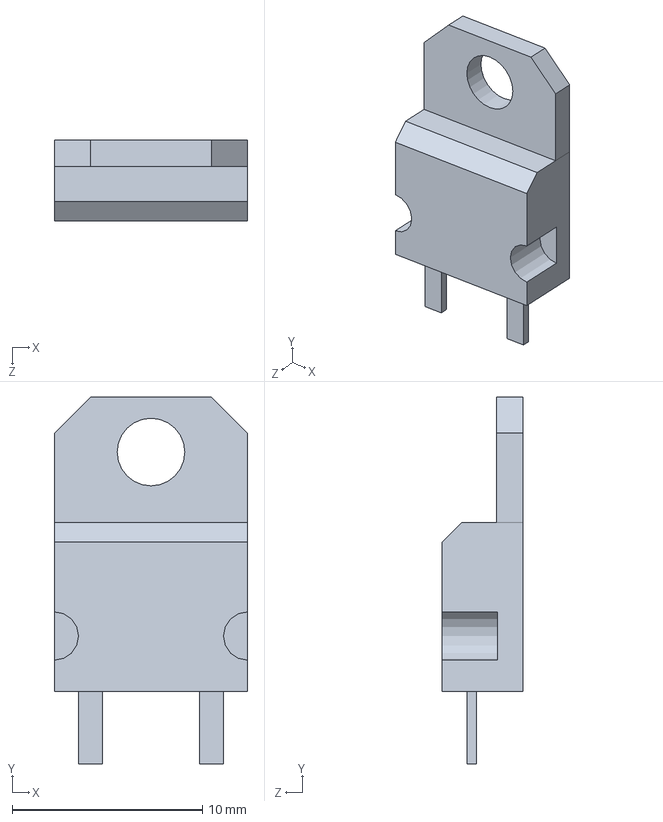
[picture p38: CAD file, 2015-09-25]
Mechanical Hardware/PCB/PCBDiode.SLDPRT
10.2 x 19.3 x 4.24 mm

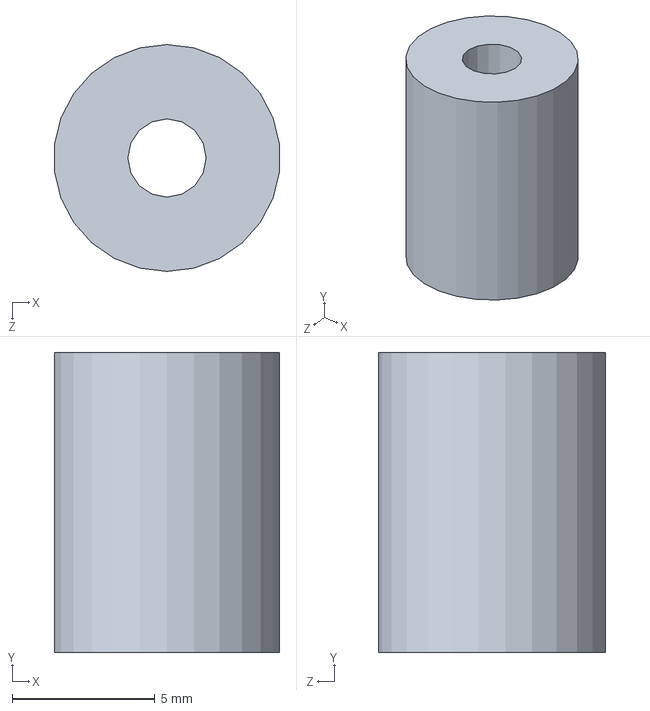
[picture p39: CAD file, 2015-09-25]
Mechanical Hardware/VariousComponents/Standoff.SLDPRT
7.89 x 10.5 x 7.95 mm

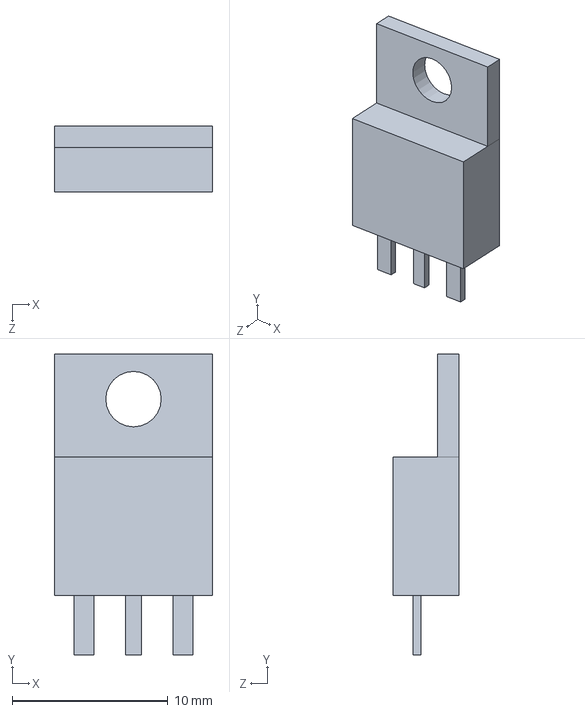
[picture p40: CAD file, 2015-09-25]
Mechanical Hardware/PCB/PCBMosfet.SLDPRT
10.2 x 19.3 x 4.24 mm

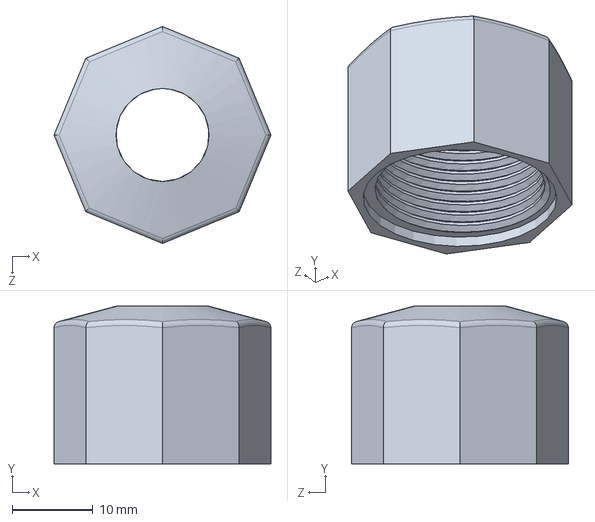
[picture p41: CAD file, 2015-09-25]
Mechanical Hardware/CableGland/GlandNutWithThread.SLDPRT
26.9 x 19.6 x 26.9 mm

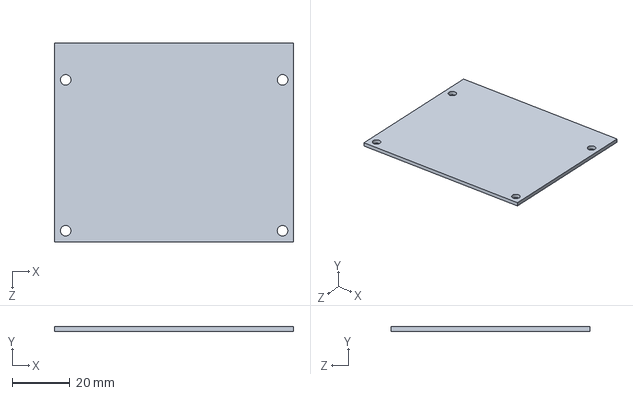
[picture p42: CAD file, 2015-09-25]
Mechanical Hardware/PCB/PCB.SLDPRT
82.5 x 1.60 x 68.6 mm

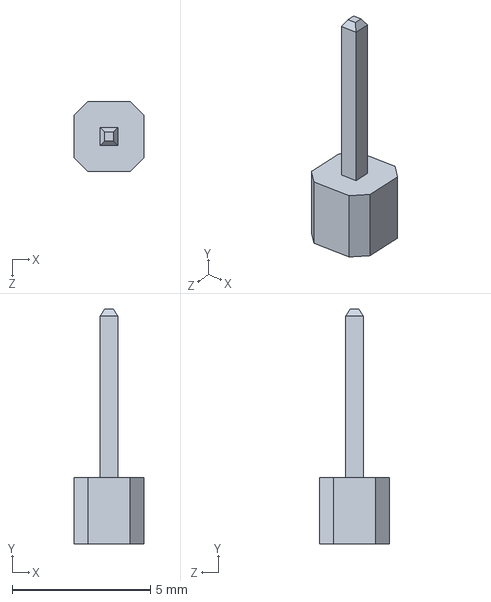
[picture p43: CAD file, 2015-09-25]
Mechanical Hardware/PCB/PCBPin.SLDPRT
2.54 x 8.51 x 2.54 mm

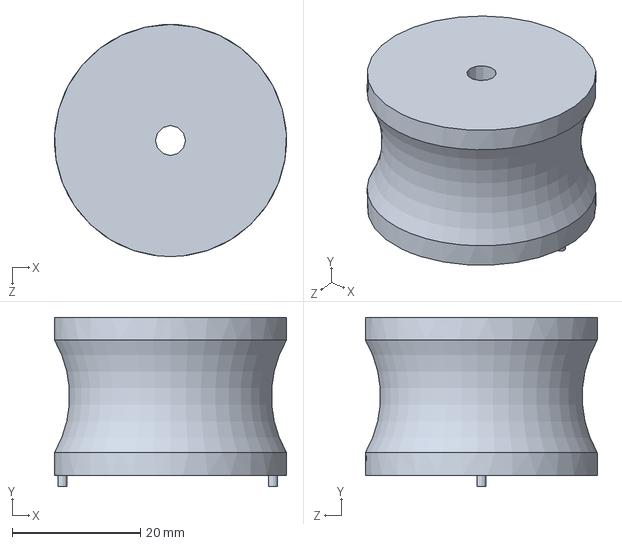
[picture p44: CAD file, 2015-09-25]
Mechanical Hardware/PCB/PCBInductor1.SLDPRT
36.2 x 26.4 x 36.2 mm

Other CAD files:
Mechanical Hardware/VariousComponents/BottomScrew.SLDPRT
Mechanical Hardware/CableGland/GlandRubberWasher.SLDPRT

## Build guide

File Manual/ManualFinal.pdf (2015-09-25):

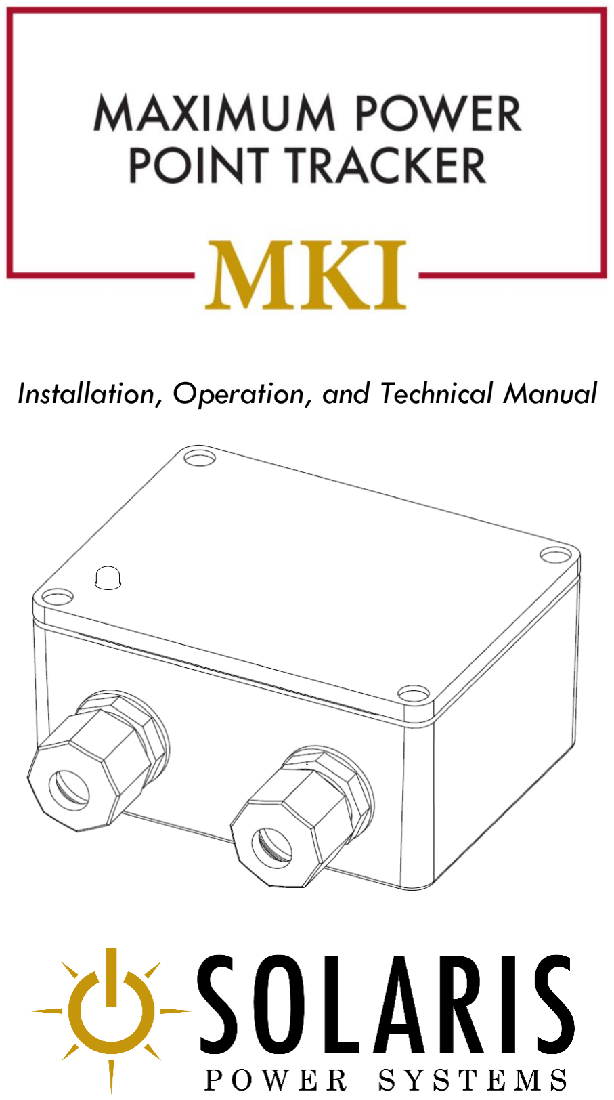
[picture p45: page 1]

## Installation, Operation, and Technical Manual

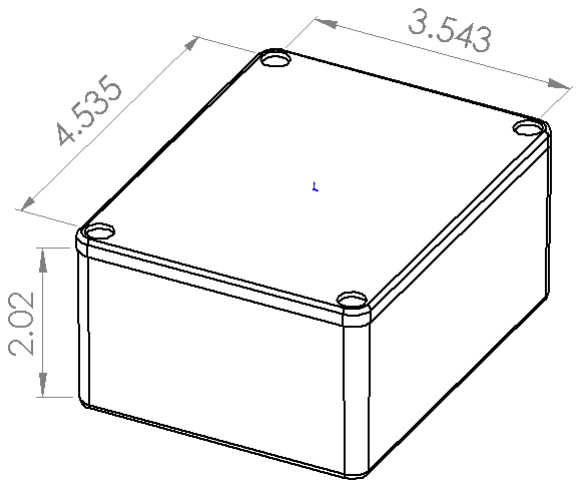
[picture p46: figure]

i

Product Dimensions

4.535” L x 3.543” W x 2.02” H

Specifications

Maximum Output Voltage: 25 Volts

Rated Load Current: 10 A

Maximum Input Voltage*: 38 Volts

*Array voltage should never exceed maximum input voltage. Refer to the PV panel documentation to determine the highest expected array Voc as defined by the lowest expected ambient temperature for the system location.

ii

## TABLE OF CONTENTS

## IMPORTANT SAFETY INSTRUCTIONS

This manual contains important safety instructions for safe and proper handling, installation, operation, and maintenance of the Maximum Power Point Tracker. Do not discard this manual.

Take note of the following symbols. They will be used throughout the manual to indicate instructions and precautions that require particular care.

WARNING: This instruction/procedure is potentially dangerous and should be carried out with great consideration. Follow the listed precautions and steps very carefully.

CAUTION: This instruction presents an important procedure for the safety and functionality of the device.

General Safety Instructions

- Read all instructions and precautions in this manual before beginning installation.
- The MPPT should be serviced only by a qualified personnel. Do not disassemble or attempt to repair the device unless you are a licensed technician.
- Disconnect all sources of power to the MPPT before installation or adjustment.
- There are no fuses inside the MPPT. Install external fuses or breakers as required.
- Confirm that all power connections are securely tightened to avoid overheating.

WARNING: Servicing instructions listed in this manual are for use by qualified personnel only. Do not perform any servicing other than that specified in the operating instructions unless you are qualified to do so. Attempting to service without proper training could result in electric shock.

WARNING: Do not disconnect live circuit. To do so could result in permanent damage to the circuit.

CAUTION: This device is not constructed to output to a battery. To do so may result in unpredictable and improper operation of the device. Output terminals should only be connected to a resistive load rated at the specifications given in this document.

## GENERAL INFORMATION

Product Description

The Solaris Power Systems Maximum Power Point Tracker MKI is a device capable of boosting the power output of a solar panel to a resistive load. The MPPT requires minimal setup and configuration, and little to no maintenance, maximizing your investment in solar panels.

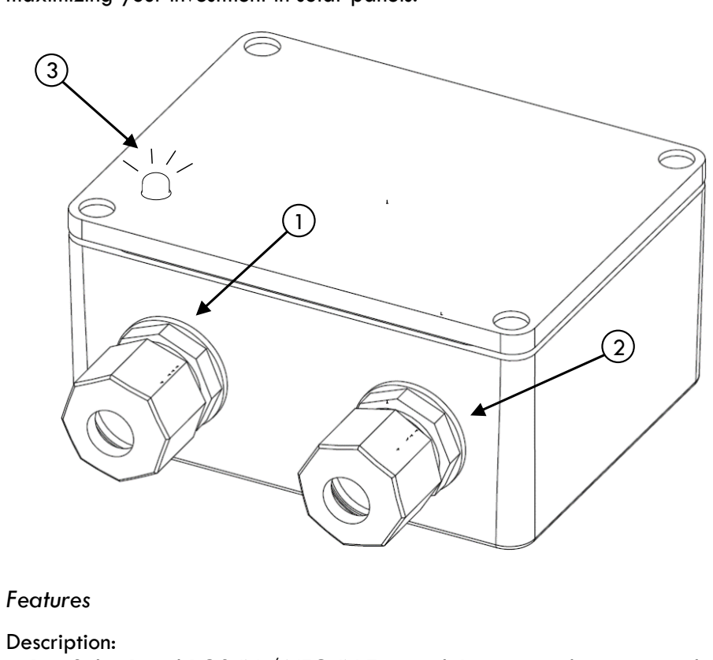
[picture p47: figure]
Features; Description:

1. Solar Panel POS-IN / NEG-IN Terminal: Positive and negative voltage terminal for solar panel input. Red wire for positive, black wire for negative.
2. Load POS-OUT / NEG-OUT Terminal: Positive and negative voltage terminal for resistive load. Red wire for positive, black wire for negative.
3. LED Indicator: Lit LED indicates device is receiving power and operating, unlit LED indicates device is not receiving power thus not operating. This LED may also assist in troubleshooting. For more information, see TROUBLESHOOTING on page 5.

## INSTALLATION INSTRUCTIONS

Read through all instructions prior to performing installation.

Mounting Instructions
- It is recommended that the MPPT MKI be located in an area with consistent airflow to avoid the possibility of overheating.
- The MPPT MKI can be mounted by two different methods.
- Standard Mount: Using the two diagonal holes in the bottom of the housing, MPPT MKI can be mounted a flat surface.
- Pole Mount: Using the two diagonal holes in the bottom of the housing, the MPPT MKI can be mounted to pole-clamping hardware.

Prior to Wiring
- Ensure that solar panel or array is rated at a total power output of no greater than 100 W.
- Ensure that the resistive load is rated for a power output of no less than 100 W.

Wiring Instructions

1. Plug negative lead from resistive load into NEG-OUT terminal.
2. Plug positive lead from resistive load into POS-OUT terminal.
3. Plug negative lead from solar panel or array into NEG-IN terminal.
4. Plug positive lead from solar panel or array into POS-IN terminal. NOTE: Upon completion of this step, the LED indicator should be lit. If so, the load will be receiving power. If not, see TROUBLESHOOTING on page 5.

WARNING: Do not connect solar panel terminals into the MPPT MKI before connecting load terminals.

## OPERATION & MAINTENANCE

LED Indication

The LED will be lit if the MPPT MKI is receiving power and operating properly. If the LED is not lit, see TROUBLESHOOTING on page 5.

Inspection & Maintenance

While the MPPT MKI is designed to be durable and weather resistant, it is recommended that it be inspected and cleaned on occasion to ensure long life.

To clean the MPPT MKI:

- Ensure no power is being supplied to the device. Unplug all leads.
- Use a damp cloth (with a small amount of soap, if desired) to wipe down the device. Be careful around the terminals, to ensure no moisture enters.
- It is not necessary to clean the inside of the device. Do not open the case unless you are qualified to do so.

## TROUBLESHOOTING

Error Indications & Causes

LED not lit

- Solar panel not providing enough power to MPPT MKI.
- Voltage regulator damaged.
- Load not connected properly.
- Panel/Array not connected properly.
- MPPT MKI malfunctioning.

Load not receiving power

- Solar panel not providing enough power to MPPT MKI.
- Load not connected properly.
- Panel/Array not connected properly.
- MPPT MKI malfunctioning.

General Troubleshooting

Before going further, be sure that you can answer ‘yes’ to all of the following questions:

- Is there a considerable amount of sunlight in view?
- Is the solar panel or array aimed toward the sunlight?
- Is the solar panel or array functional?
- If using an array, are all panels interconnected properly?
- Are all cables good?
- Are connections to solar panel(s) snug?
- Are cables connected to proper inputs on MPPT MKI? See Wiring Instructions on page 3.
- Are connections to MPPT MKI snug?
- Is load functioning properly? Test with other power source if necessary.

If you can answer ‘yes’ to all of these questions, and your MPPT MKI is still not functional, please contact a qualified service technician.

## SERVICING & REPAIR

CAUTION: Do not attempt to service or repair the MPPT MKI unless you are a qualified technician. To do so could result in harm to yourself or to the device.

Debugging Pins

The PORT 1 header pins located at the bottom of the circuit board (relative to the orientation shown in the diagram below) are intended for debugging. The connections are given below.

- Pin 0: Input current sensor
- Pin 1: Input voltage sensor
- Pin 2: Output current sensor
- Pin 3: Output voltage sensor
- Pin 4: MOSFET control

Disassembly

1. Ensure no cables are plugged into the device.
2. Allow device to cool down if recently operating.
3. Remove (4) corner screws on housing lid.
4. Carefully tilt open lid and disconnect two wires attached to lid from MPPT MKI circuit board.
5. Remove lid.
6. Loosen (4) screws on screw terminals to release wire connecting printed circuit board terminals to cable glands.
7. Remove (4) screws securing printed circuit board to housing.
8. Remove circuit board from housing by grabbing the board itself, not the components.

Integrated Circuit Replacement

To replace an integrated circuit (IC) within the MPPT MKI, follow the steps given below.

1. Follow steps 1-5 of the Disassembly section above.
2. Locate faulty IC. Use printed circuit board diagram shown on the following page if necessary.
3. Use IC puller to remove IC.
4. Insert replacement IC, ensuring it is facing the proper direction.
5. Reassemble device. NOTE: For wires attached to lid: red goes to right LED pin, purple goes to left LED pin.

Through-Hole Component Replacement

1. Follow steps 1-8 of the Disassembly section above.
2. Locate faulty component. Use printed circuit board diagram shown on the following page if necessary.

3. Remove faulty component using a soldering iron or other appropriate heat tool, being careful not to damage other components.
4. Solder in replacement component. If polarized, ensure proper direction.
5. Reassemble device. NOTE: For wires attached to lid: red goes to right LED pin, purple goes to left LED pin.

Printed Circuit Board Layout

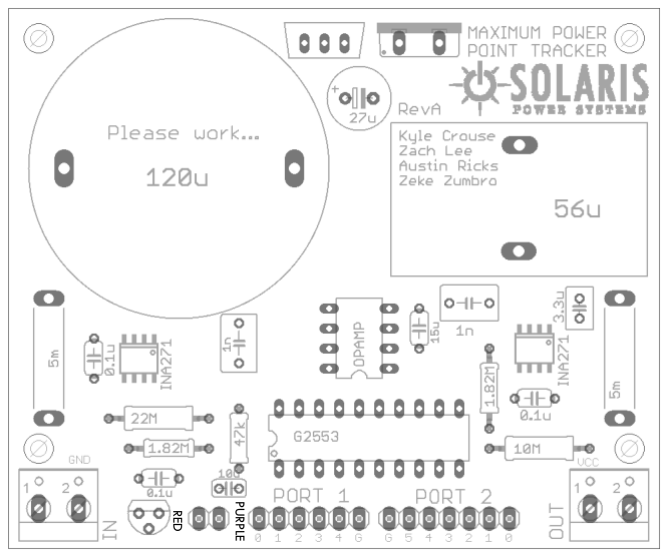
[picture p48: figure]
PURPLE; RED

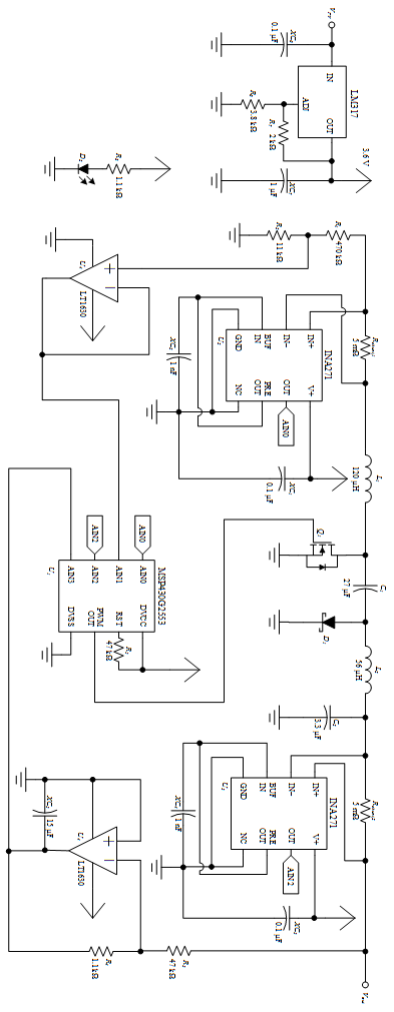
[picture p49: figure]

Circuit Schematic

Bill of Materials

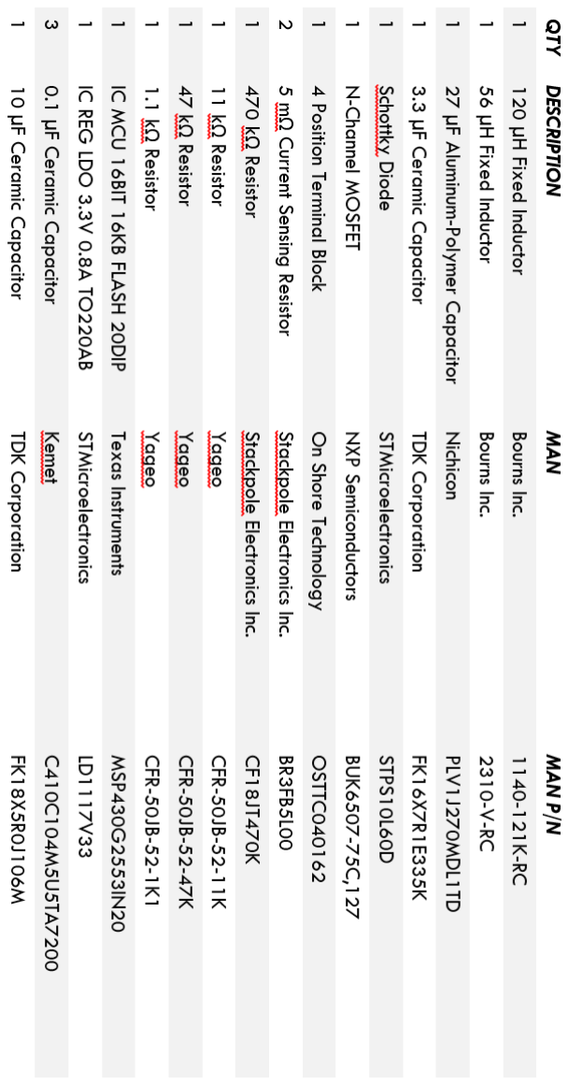
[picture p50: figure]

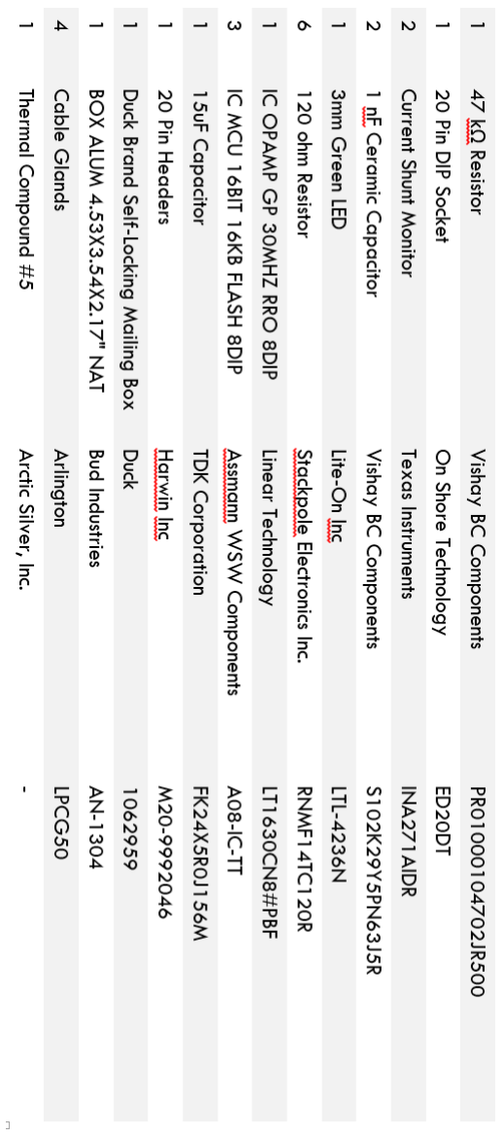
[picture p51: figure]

## NOTES

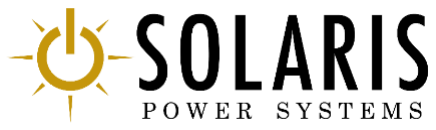
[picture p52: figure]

© Solaris Power Systems 2015 Maximum Power Point Tracker MKI™ CEO Zachary Lee
COO Kyle Crouse
Division Leader Zeke Zumbro Fighter Pilot Austin Ricks

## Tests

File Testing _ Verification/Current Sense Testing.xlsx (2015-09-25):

Output Voltage (V) | Current (A) | Theoretical | ADC
0.028 | 0.1 | 1.00E-02 | 4
0.0554 | 0.2003 | 2.00E-02 | 11 | Linear fit | current = 0.3795*voltage - 0.0204
0.17 | 0.49965 | 5.00E-02 | 34
0.256 | 0.75 | 7.50E-02 | 55
0.357 | 1 | 0.1 | 79
0.445 | 1.25 | 0.125 | 99
0.55 | 1.5 | 0.15 | 120
0.642 | 1.75 | 0.175 | 140
0.741 | 2 | 0.2 | 160
0.84 | 2.25 | 0.225 | 180
Testing with NEW PCB
0 | 5
0.5 | 34 | 29
1 | 65 | 31
1.5 | 105 | 40
2 | 140 | 35
2.5 | 174 | 34

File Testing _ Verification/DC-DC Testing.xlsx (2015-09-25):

 |  |  |  |  |  |  | Resistor Value | 10.15
Input |  |  | Desired Output |  | Measure Ouput | Xantrex (0-44V)
Voltage | Current | Duty Cycle | Voltage |  | Voltage | Current | Power
6.00 | 0.280 | 0.40 | 4.00 |  | 3.00 | 0.30 | 0.89
7.00 | 0.750 | 0.50 | 7.00 |  | 5.79 | 0.57 | 3.30
7.00 | 1.690 | 0.60 | 10.00 |  | 8.60 | 0.85 | 7.29
12.00 | 2.450 | 0.55 | 14.00 |  | 14.00 | 1.38 | 19.31
 |  |  |  |  |  | 0.00 | 0.00
 |  |  |  |  |  | 0.00 | 0.00
2.23 Ohm Resistor
Voltage | Duty Cycle | Ideal Out | Measured Out
2.00 | 0.500 | -2.00 | -0.85
2.50 | 0.500 | -2.50 | -1.11
3.00 | 0.500 | -3.00 | -1.42
3.50 | 0.500 | -3.50 | -1.78
4.00 | 0.500 | -4.00 | -2.15
4.50 | 0.500 | -4.50 | -2.67
5.00 | 0.500 | -5.00 | -3.20
5.50 | 0.500 | -5.50 | -3.64
6.00 | 0.500 | -6.00 | -4.17
Vin | Duty Cycle | Ideal | LTSPICE | Measured
5.00 | 0.250 | -1.67 | -1.38 | -1.06
5.00 | 0.375 | -3.00 | -2.62 | -2.22
5.00 | 0.500 | -5.00 | -4.53 | 3.91
5.00 | 0.625 | -8.33 | -7.72 | -6.83

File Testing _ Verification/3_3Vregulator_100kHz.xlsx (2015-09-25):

MPPT (10) |  |  |  |  |  |  | BASELINE (9) |  |  |  |  |  |  |  | MPPT (10) |  |  |  |  |  |  | BASELINE (9) |  |  |  |  |  |  |  | MPPT (9) |  |  |  |  |  |  | BASELINE (10)
Time | Voltage | Square Voltage | INST Power | Mean | RMS | AVG Power | Time | Voltage | Square Voltage | INST Power | Mean | RMS | AVG Power | %INCREASE | Time | Voltage | Square Voltage | INST Power | Mean | RMS | AVG Power | Time | Voltage | Square Voltage | INST Power | Mean | RMS | AVG Power | %Increase | Time | Voltage | Square Voltage | INST Power | Mean | RMS | AVG Power | Time | Voltage | Square Voltage | INST Power | Mean | RMS | AVG Power | %INCREASE | %INCREASE (9) | %INCREASE (10)
0 | 7.04 | 49.5616 | 8.192 | 45.92878933 | 6.77707823 | 7.591535427 | 0 | 5.2 | 27.04 | 4.469421488 | 27.25120853 | 5.22026901 | 4.504331989 | 68.53854124 | 0 | 6.96 | 48.4416 | 8.006876033 | 44.70169031 | 6.685932269 | 7.388709142 | 0 | 4.64 | 21.5296 | 3.55861157 | 25.14961351 | 5.014939034 | 4.156960911 | 77.74305077 | 0 | 5.76 | 33.1776 | 5.483900826 | 34.14001778 | 5.842945984 | 5.642978145 | 0 | 6.16 | 37.9456 | 6.272 | 36.15016107 | 6.012500401 | 5.975233234 | -5.560537573 | 0.3574768361 | 0.2365557716
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

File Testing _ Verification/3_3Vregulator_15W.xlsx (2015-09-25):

MPPT (10) |  |  |  |  |  |  | BASELINE (9) |  |  |  |  |  |  |  | MPPT (10) |  |  |  |  |  |  | BASELINE (9) |  |  |  |  |  |  |  | MPPT (9) |  |  |  |  |  |  | BASELINE (10)
Time | Voltage | Square Voltage | INST Power | Mean | RMS | AVG Power | Time | Voltage | Square Voltage | INST Power | Mean | RMS | AVG Power | %INCREASE | Time | Voltage | Square Voltage | INST Power | Mean | RMS | AVG Power | Time | Voltage | Square Voltage | INST Power | Mean | RMS | AVG Power | %Increase | Time | Voltage | Square Voltage | INST Power | Mean | RMS | AVG Power | Time | Voltage | Square Voltage | INST Power | Mean | RMS | AVG Power | %INCREASE | %INCREASE (9) | %INCREASE (10)
0 | 7.04 | 49.5616 | 8.192 | 45.92878933 | 6.77707823 | 7.591535427 | 0 | 5.2 | 27.04 | 4.469421488 | 27.25120853 | 5.22026901 | 4.504331989 | 68.53854124 | 0 | 6.96 | 48.4416 | 8.006876033 | 44.70169031 | 6.685932269 | 7.388709142 | 0 | 4.64 | 21.5296 | 3.55861157 | 25.14961351 | 5.014939034 | 4.156960911 | 77.74305077 | 0 | 5.76 | 33.1776 | 5.483900826 | 34.14001778 | 5.842945984 | 5.642978145 | 0 | 6.16 | 37.9456 | 6.272 | 36.15016107 | 6.012500401 | 5.975233234 | -5.560537573 | 35.74768361 | 23.65557716
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

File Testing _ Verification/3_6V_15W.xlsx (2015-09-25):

MPPT (10) |  |  |  |  |  |  |  | BASELINE (9) |  |  |  |  |  |  |  |  | MPPT (9) |  |  |  |  |  |  |  | BASELINE (10)
Time | Voltage | Square Voltage | INST Power | M AVG POWER | Mean | RMS | AVG Power | Time | Voltage | Square Voltage | INST Power | M AVG POWER | Mean | RMS | AVG Power | %Increase | Time | Voltage | Square Voltage | INST Power | M AVG POWER | Mean | RMS | AVG Power | Time | Voltage | Square Voltage | INST Power | M AVG POWER | Mean | RMS | AVG Power | % Increase (9) | % Increase (10)
0 | 7.2 | 51.84 | 8.568595041 | #N/A | 48.73360782 | 6.980946055 | 8.055141789 | 0 | 5.04 | 25.4016 | 4.19861157 | #N/A | 26.45279004 | 5.14322759 | 4.372361991 |  | 0 | 6 | 36 | 5.950413223 | #N/A | 37.48606862 | 6.122586759 | 6.1960444 | 0 | 6.32 | 39.9424 | 6.602049587 | #N/A | 37.84576284 | 6.151890997 | 6.255497991 | 41.70931898 | 28.7689933
0.2 | 6.8 | 46.24 | 7.642975207 | #N/A |  |  |  | 0.2 | 4.88 | 23.8144 | 3.936264463 | #N/A |  |  |  |  | 0.2 | 5.84 | 34.1056 | 5.637289256 | #N/A |  |  |  | 0.2 | 6.16 | 37.9456 | 6.272 | #N/A
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

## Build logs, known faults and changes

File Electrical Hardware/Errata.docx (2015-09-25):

- Port 1 header pin 4 labeled incorrectly (should be 6)
- Opamp pins connected wrong. Error with device definitions.
- Increase size of terminal blocks for wire gauge suited for amperage specs
- Voltage regulator doesn’t work
- Different resistor values

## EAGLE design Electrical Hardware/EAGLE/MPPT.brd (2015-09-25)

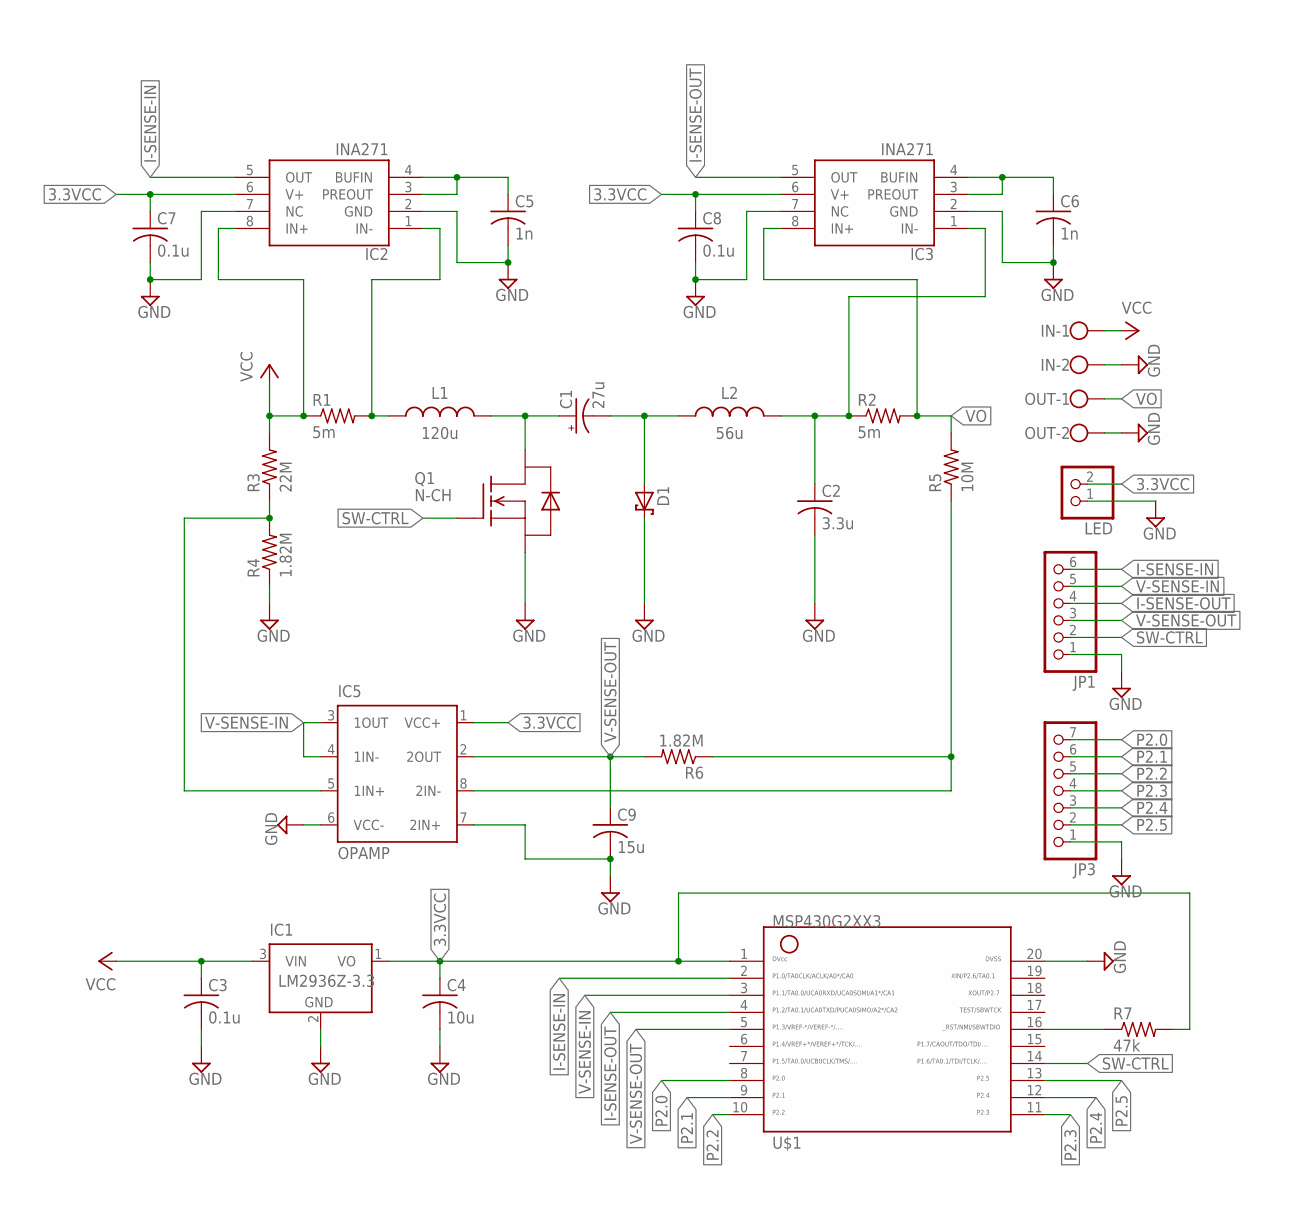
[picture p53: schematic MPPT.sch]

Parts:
C1: 27u; E3,5-8
C2: 3.3u; C02,5-03,5X05,5
C3, C7, C8: 0.1u; C050-024X044
C4: 10u; C025-024X044
C5, C6: 1n; C050-045X075
C9: 15u; C050-024X044
D1: SCHOTTKY-DIODEVERTICAL; TO220ACS
IC1: LM2936Z-3.3; TO92
IC2, IC3: INA271; SO08
IC5: OPAMP; DIL08
IN: W237-102
JP1: PINHD-1X6; 1X06
JP3: PINHD-1X7; 1X07
L1: 120u; IND-1140-121K-RC
L2: 56u; IND-2310-RC-VERT
LED: PINHD-1X2; 1X02
OUT: W237-102
Q1: N-CH; TO220-VERT
R1, R2: 5m; BR3-CURRENT-SENSE
R3: 22M; 0309/12
R4, R6: 1.82M; 0207/10
R5: 10M; 0309/12
R7: 47k; 0207/7
U$1: G2553; N20

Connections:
3.3VCC: C4.1, C7.1, C8.1, IC1.1 (VO), IC2.6 (V+), IC3.6 (V+), IC5.1 (VCC+), LED.2, R7.2, U$1.1
GND: C2.2, C3.2, C4.2, C5.2, C6.2, C7.2, C8.2, C9.2, D1.C, IC1.2 (GND), IC2.2 (GND), IC2.7 (NC), IC3.2 (GND), IC3.7 (NC), IC5.6 (VCC-), IC5.7 (2IN+), IN.2, JP1.1, JP3.1, LED.1, OUT.2, Q1.P$3 (S), R4.1, U$1.20
I-SENSE-IN: IC2.5 (OUT), JP1.6, U$1.2
I-SENSE-OUT: IC3.5 (OUT), JP1.4, U$1.4
unnamed: C1.+, L1.P$2, Q1.P$2 (D)
unnamed: C1.-, D1.A, L2.P$1
unnamed: R7.1, U$1.16
unnamed: IC5.5 (1IN+), R3.1, R4.2
unnamed: IC5.8 (2IN-), R5.1, R6.1
unnamed: IC2.1 (IN-), L1.P$1, R1.P$2 (2)
unnamed: C2.1, IC3.1 (IN-), L2.P$2, R2.P$1 (1)
unnamed: C5.1, IC2.3 (PREOUT), IC2.4 (BUFIN)
unnamed: C6.1, IC3.3 (PREOUT), IC3.4 (BUFIN)
P2.0: JP3.7, U$1.8
P2.1: JP3.6, U$1.9
P2.2: JP3.5, U$1.10
P2.3: JP3.4, U$1.11
P2.4: JP3.3, U$1.12
P2.5: JP3.2, U$1.13
SW-CTRL: JP1.2, Q1.P$1 (G), U$1.14
V-SENSE-IN: IC5.3 (1OUT), IC5.4 (1IN-), JP1.5, U$1.3
V-SENSE-OUT: C9.1, IC5.2 (2OUT), JP1.3, R6.2, U$1.5
VCC: C3.1, IC1.3 (VIN), IC2.8 (IN+), IN.1, R1.P$1 (1), R3.2
VO: IC3.8 (IN+), OUT.1, R2.P$2 (2), R5.2

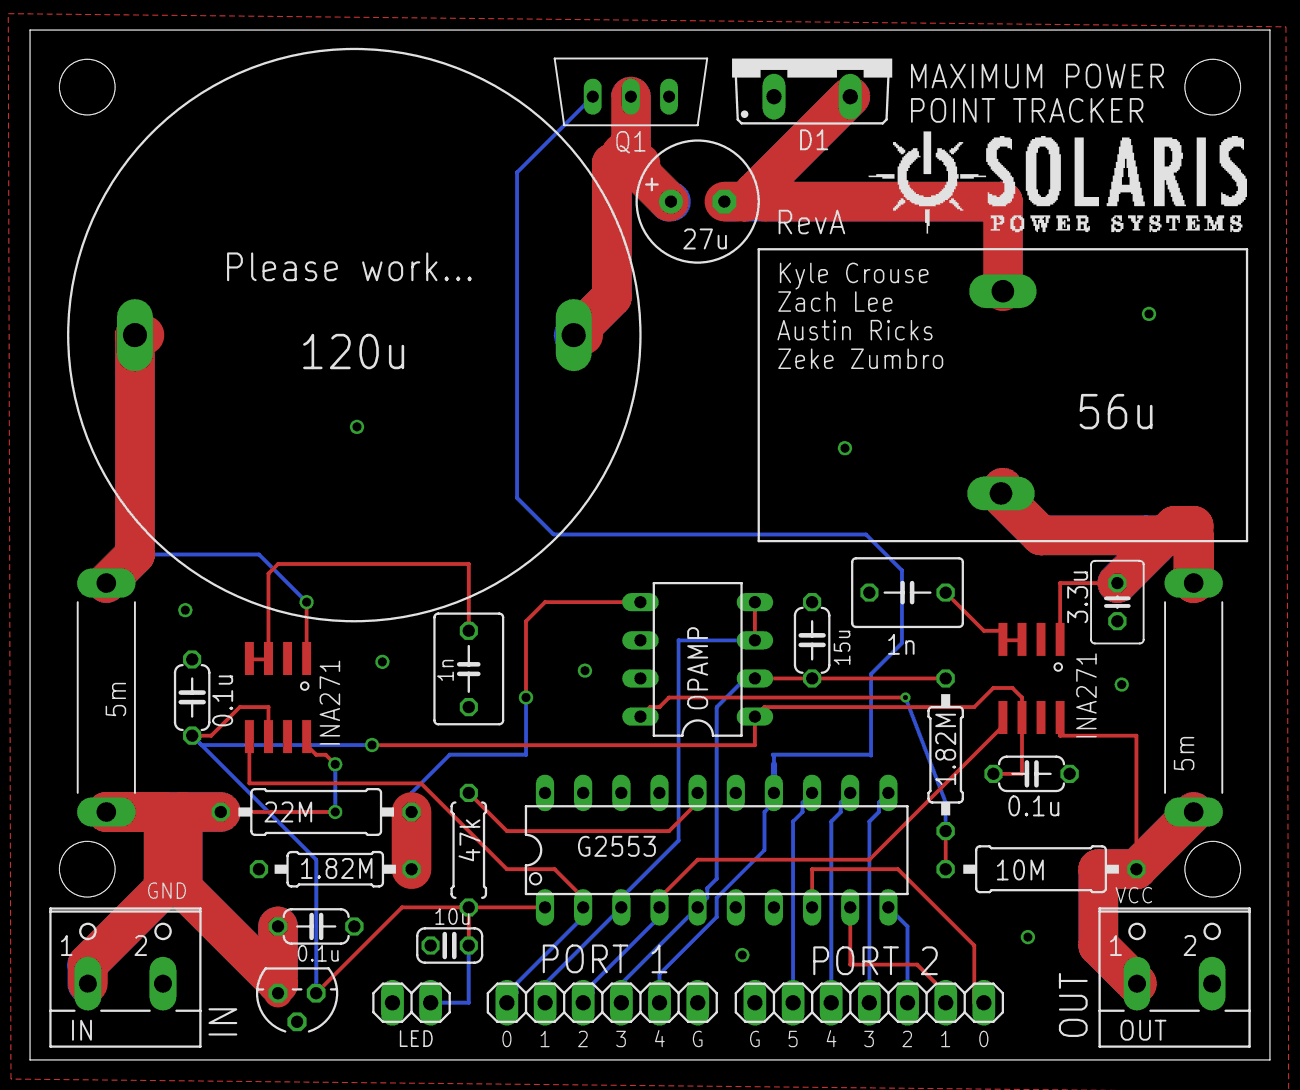
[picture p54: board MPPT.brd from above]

Board: 2 copper layers, 82.6 x 68.6 mm, 30 parts (0 on the bottom side), 24 nets.

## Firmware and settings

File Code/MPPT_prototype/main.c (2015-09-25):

#include <msp430.h>
#include <stdio.h>
//definitions

#define step_size 1
#define PWM_freq 160 									//set frequency to 100 kHz
#define TOP_DUTY 128									//set max duty cycle to 80%
#define BOTTOM_DUTY 32									//set min duty cycle to 20%
#define MAX_CURR 5.0									//set max curr to 5 A
#define DELAY 1500										// 0.5s * (12000/4)Hz
#define TIMER_ON 	TA1CTL=TASSEL_1+MC_1+ID_2			// use ACLK, timer on, divide by 4
#define TIMER_OFF 	TA1CTL=TASSEL_1+MC_0+ID_2			// use ACLK, timer off, divide by 4

// Global Variables
unsigned int adc[32][4] = {0};							//array to store adc values
float curr_in = 0;										//variable to store current in
float volt_in = 0;										//variable to store voltage in
float curr_out = 0;										//variable to store current out
float volt_out = 0;										//variable to store voltage out

unsigned int duty_cycle = 80;							//variable to store current duty cycle, default to 50%

typedef enum {inc, dec} direction;						//enumeration to handle increasing and decreasing state for P&O algorithm
direction dir = inc;
unsigned char updown = 1;								// 0 is down, 1 is up
volatile float vo = 0;
volatile float io = 0;
volatile float po = 0;

//Function Prototypes
void Setup_MSP(void);									// Setup watchdog timer, clockc, ADC ports
void Setup_ADC(void);									// Setup input channels and sequences,
void Setup_PWM(void);									// Setup output pin, PWM freq, initial duty cycle, PWM mode, and clock setup
void Setup_Timer(void);									// Setup timer to allow processor to enter low power mode between adjustments.
void Read_ADC(void);									// This function reads the ADC and stores values
char Circuit_Breaker(void);								// returns false if current values are within CURR_MAX, true otherwise
void PandO(void);										// function which adjusts duty cycle via the Perturb and Observe Algorithm
void PandO2(void);										// simplified PandO algorithm
void IncCond(void);										// function which adjusts duty cycle via the IncCond Algorithm
void IncCond2(void);									// IncCond algorithm using i/v equations
void SetPoint(float point);								// sets output voltage to a certain point

int main(void)
{
 	Setup_MSP();										//settings for the MSP in general
	Setup_ADC();										//settings for ADC
	Setup_PWM();										//settings for PWM
	Setup_Timer();
	while (1)
	{
		Read_ADC();										// get current measurements from ADC and convert to voltages and currents
		PandO();										// adjust operating point if needed using Perturb and Observe Algorithm
		TIMER_ON;										// set timer 
		LPM0;
	}
}

//Set up basic configuration of MSP430
void Setup_MSP(void)
{
	  WDTCTL = WDTPW + WDTHOLD;                 		// Stop WDT
	  BCSCTL1 = CALBC1_16MHZ;     						// Set range
	  DCOCTL = CALDCO_16MHZ;     						// Set DCO step and modulation
	  __enable_interrupt();								// Enable Interupts
}

//Set up Analog to Digital Converter
void Setup_ADC(void)
{
	ADC10CTL1 = INCH_3 + CONSEQ_3;            					// A3/A2/A1/A0, multi sequence
	ADC10CTL0 = ADC10SHT_3 + MSC + ADC10ON + ADC10IE + REFON + SREF_1;
	P1DIR = 0;													// all inputs
	ADC10AE0 |= BIT0 + BIT1 + BIT2 + BIT3;                      // Disable digital I/O on P1.0 to P1.3
	ADC10DTC1 = 128;                         					// 64 conversions
}

//Set up Pulse Width Modulation
void Setup_PWM(void)
{
	P1DIR |= BIT6;              								// PWM output pin
	P1SEL |= BIT6;              								// P1.6 controlled by Pulse width modulation
	TA0CCR0 = PWM_freq;											// PWM Frequency is 100 kHz
	TA0CCR1 = duty_cycle;										// Initial Duty Cycle is 50%
	TA0CCTL1 = OUTMOD_7;										// set/reset mode
	TACTL = TASSEL_2 + MC_1; 									// Chooses SMCLK, and Up Mode.
}

//Set up timer for sleeping between readings
void Setup_Timer(void)
{
	BCSCTL3 |= LFXT1S_2;										// set ACLK to use VLO
	TA1CCR0 = DELAY;											// set the timer value
	TA1CCTL0 = CCIE;											// enable the interrupts from TimerA0 CC0
	TIMER_OFF;													// stop the timer
}

// Timer A1 interrupt service routine
#pragma vector=TIMER1_A0_VECTOR
__interrupt void Timer_A1 (void)
{
	TIMER_OFF;													//Disable the times
	__low_power_mode_off_on_exit();								//Exit low power mode in order to take reading and change duty cycle
}

//Function to read from the ADC
//ADC values from 4 pins are taken 32 time then averaged
//Values are returned through global variables
void Read_ADC(void)
{
    ADC10CTL0 &= ~ENC;
    while (ADC10CTL1 & BUSY);              						// Wait if ADC10 core is active
    ADC10SA = (unsigned int)adc;								// Copies data in ADC10SA to unsigned int adc array
    ADC10CTL0 |= ENC + ADC10SC;             					// Sampling and conversion start

    __bis_SR_register(CPUOFF + GIE);        					// LPM0, wait for ADC to read, ADC10_ISR will force exit
       volatile int i = 0;										// variable for for loop
    volatile unsigned int curr_in_sum = 0;						// store sum of curr_in
    volatile unsigned int volt_in_sum = 0;						// store sum of volt_in
    volatile unsigned int curr_out_sum = 0;						// store sum of curr_out
    volatile unsigned int volt_out_sum = 0;						// store sum of volt_out
    for (i = 31; i>=0; i--)										//read through all 16 samples of each channel
    {															//create a sum of all the samples of each input for average
    	curr_in_sum += adc[i][3];
    	volt_in_sum += adc[i][2];
    	curr_out_sum += adc[i][1];
    	volt_out_sum += adc[i][0];
    }
    //divide each sum by 16 to get the average
    curr_in = (curr_in_sum / 32)*0.01346 + 0.01594;				//equation to calculate curr_in
    volt_in = (volt_in_sum / 32)*0.0661 - 0.27437;				//equation to calculate volt_in
    curr_out = (curr_out_sum / 32)*0.013 + 0.019945;			//equation to calculate curr_out
    volt_out = (volt_out_sum / 32)*0.0614 - 0.0524;				//equation to calculate volt_out
}

// ADC10 interrupt service routine
#pragma vector=ADC10_VECTOR
__interrupt void ADC10_ISR(void)
{
	__bic_SR_register_on_exit(CPUOFF);        					// Clear CPUOFF bit from 0(SR)
}

// Implementation of Perturb and Observe Algorithm 
void PandO(void)
{
	volatile float p = curr_in*volt_in;							// multiply current times voltage to get power, use long since multiplication could overflow an int16
	//volatile float p = curr_out*volt_out;
	switch (dir)												// switch based on whether the the duty cycle was last incremented or decremented
	{
		case inc:												// if incremented
			if (p > po)											// if power has increased
			{
				if (duty_cycle < TOP_DUTY)
				{
					duty_cycle += step_size;					// continue incrementing duty cycle
				}
				else
				{
					duty_cycle -= step_size;					// decrement duty cycle
					dir = dec;
				}
			}
			else if (p < po)									// if power has decreased
			{
				if (duty_cycle > BOTTOM_DUTY)
				{
					duty_cycle -= step_size;					// decrement duty cycle
					dir = dec;									// change direction to dec
				}
				else
				{
					duty_cycle += step_size;					// if power has increased
					dir = inc;									// change direction to inc
				}

			}
			break;
		case dec:												// if decremented
			if (p > po)											// if power has increased
			{
				if (duty_cycle > BOTTOM_DUTY)
				{
					duty_cycle -= step_size;					// decrement duty cycle
				}
				else
				{
					duty_cycle += step_size;					// if power has increased
					dir = inc;									// change direction to inc
				}
			}
			else if (p < po)									// if power has decreased
			{
				if (duty_cycle < TOP_DUTY)
				{
					duty_cycle += step_size;					// if power has increased
					dir = inc;									// change direction to inc
				}
				else
				{
					duty_cycle -= step_size;					// decrement duty cycle
					dir = dec;
				}
			}
			break;
	}
	TA0CCR1 = duty_cycle;										//update duty cycle
	po = p;														// store power to compare in next iteration
}

//Not yet implemented
//Would stop DC-DC converter if an over current event occurred
//Currently no way to protect against over voltage
char Circuit_Breaker(void)
{
	if (curr_in > MAX_CURR || curr_out > MAX_CURR)
	{
		duty_cycle = 0;
		TA0CCR1 = duty_cycle;										//update duty cycle
		return 1;
	}
	else
	{
		return 0;
	}
}
